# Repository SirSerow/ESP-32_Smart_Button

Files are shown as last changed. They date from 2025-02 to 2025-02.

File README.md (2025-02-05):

# Smart Button with ESP32

## Overview
This project is a **Smart Button** based on the ESP32 microcontroller. The purpose of the project is to make PC operation easy and understandable for older people. With the help of the button, users can trigger predefined actions on their computer, such as opening applications, changing settings, or sending messages.The device is designed to function as a wireless communication interface for triggering predefined actions. The button integrates **ESP-NOW**, **Wi-Fi**, **battery monitoring**, and an **OLED display** for visual feedback. The project includes both **firmware** (ESP32-side) and a **software application** (computer-side) based on C# to control the computer running Windows OS.

## Features
- **ESP-NOW Wireless Communication:** Enables low-latency, direct device-to-device communication.
- **OLED Display (SSD1351, SPI):** Provides visual feedback for the button's status and received commands.
- **Battery Monitoring:** Uses ADC calibration to estimate battery percentage.
- **External Power Detection:** Automatically detects external power and adjusts behavior.
- **Sleep Mode for Power Saving:** The device enters deep sleep when inactive for a certain period.
- **Configurable Timeout Alerts:** Notifies when the button loses connection.
- **ESP-NOW & UART Communication:** Supports both wireless peer-to-peer messaging and wired serial communication.
- **Computer-Side Application:** Monitors the button's status, performs actions on the computer and has an user interface for setting up button actions.

## Hardware Components
- **ESP32 Development Board**
- **SSD1351 OLED Display (SPI)**
- **Push Button**
- **Battery & Charging Circuit**
- **I2C Communication (SDA: GPIO21, SCL: GPIO22)**
- **Status LED (GPIO14)**
- **External Power Detection (GPIO39)**

## Circuit Diagram
The detailed schematic of the **Smart Button** circuit can be found in the [doc folder](./doc/Board_Schematic.pdf).

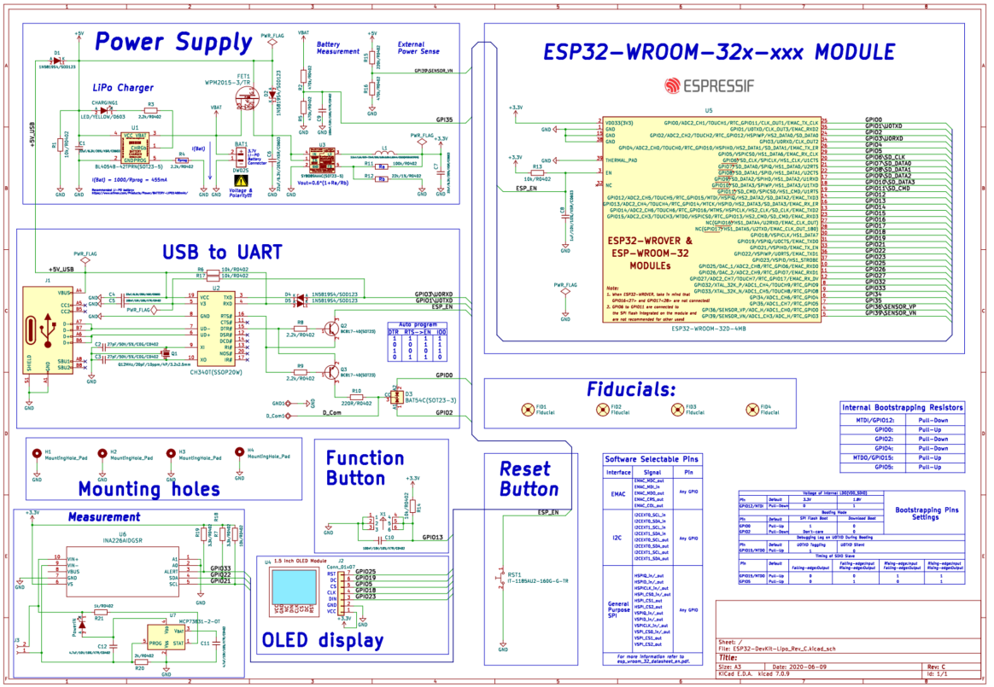
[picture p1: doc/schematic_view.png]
Schematic


## PCB Layout
The project includes a fully designed two-layer PCB for manufacturing. Components are placed exclusevily on top layer to lower the assebly cost and simplify the repairs. For similar reason, in terms of component enclosure type, the preference was given to SMD components. Layout files are available in the hardware folder.

<div align="center" style="margin-top: 30px; margin-bottom: 20px;">
    <b>Top View:</b><br>
    <div style="margin-top: 20px;">
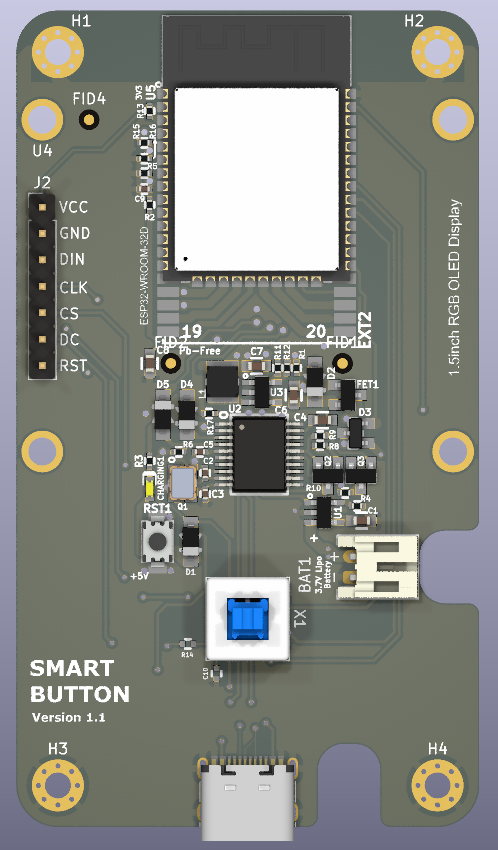
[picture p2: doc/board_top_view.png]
PCB Top
        
    </div>
</div>

<div align="center" style="margin-top: 30px; margin-bottom: 20px;">
    <b>Bottom View:</b><br>
    <div style="margin-top: 20px;">
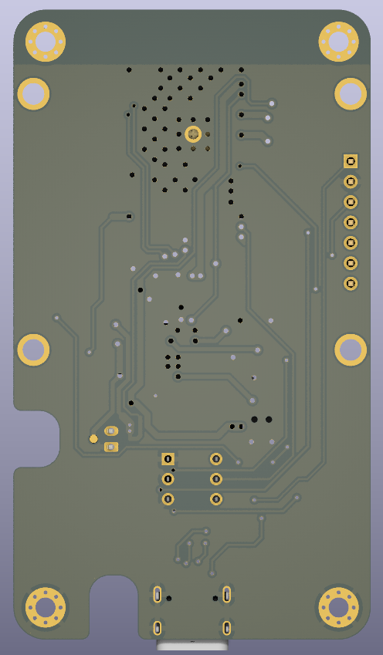
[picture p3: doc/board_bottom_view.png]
PCB Bottom
        
    </div>
</div>

<div align="center" style="margin-top: 30px; margin-bottom: 20px;">
    <b>Side View:</b><br>
    <div style="margin-top: 20px;">
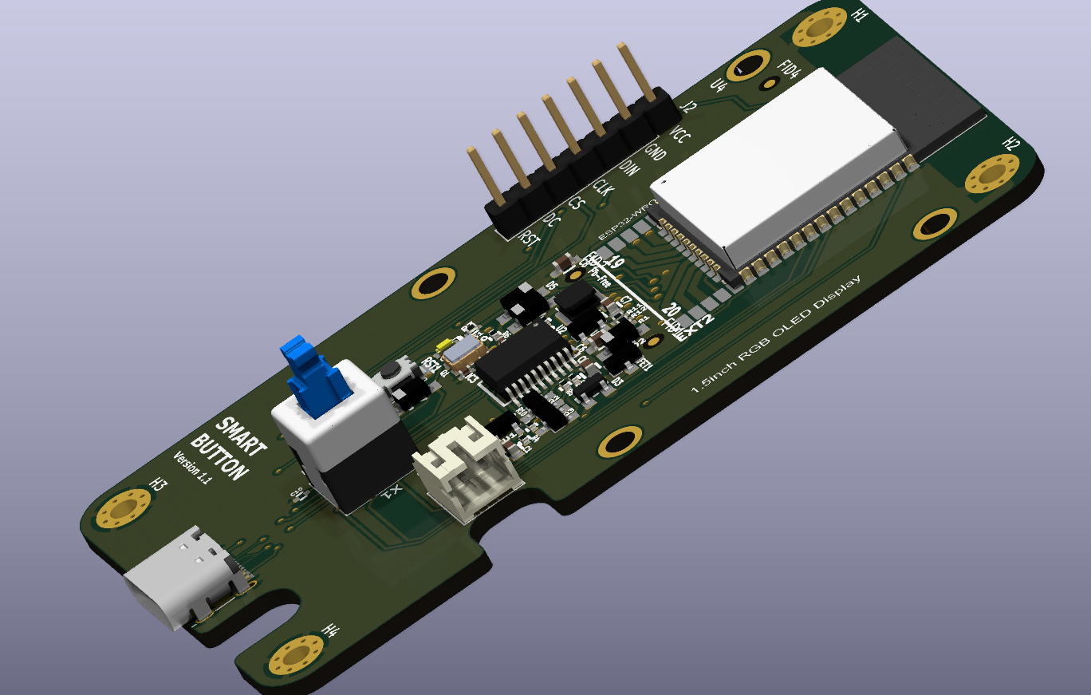
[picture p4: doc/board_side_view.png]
PCB Side
        
    </div>
</div>

## Software Features
The computer-side application for the Smart Button enhances its usability by allowing users to configure and automate various actions triggered by the button press. The application runs as a Windows GUI-based tool, providing an intuitive interface for setting up and managing button actions. 

Since the application is designed to run on Windows, it is developed using C# and .NET Framework. The application communicates with the Smart Button via a serial connection (UART). The framework and communication were chosen to be simple and easy to use and to fit older systems with limited resources.

There are two ways to connect the Smart Button to the computer:
1. **Wired Connection:** The Smart Button is connected to the computer via a USB cable, and the application communicates with the button over a serial port.
2. **Wireless Connection:** The Smart Button communicates with the computer over a wireless connection using the ESP32's ESP-NOW protocol. ESP32 reciever is connected to the computer via USB cable. 

#### **Key Features**
1. **Serial Communication with the Smart Button**
   - Automatically detects the Smart Button via **USB serial ports**.
   - Monitors and logs communication between the button and the PC.
   - Detects button presses and relays corresponding actions.

2. **Configurable Button Actions**
   - Users can assign different actions to the button, such as:
     - **Opening a website (link)**
     - **Making a phone call**
     - **Sending an email**
     - **Launching an application**
   - Each button press executes the assigned function immediately.

3. **Quick Action Setup & Profiles**
   - **User-defined actions** can be assigned to different buttons in the UI.
   - **Multiple configuration profiles** allow quick switching between different use cases.
   - **Preloaded default configurations** available on first launch.

4. **Real-Time Device Status Monitoring**
   - Displays the **current connection status** of the button.
   - Tracks the **last received ping** from the button to ensure connectivity.
   - Shows **battery status** if supported by the Smart Button.

5. **Graphical User Interface (GUI)**
   - Provides a **Windows Forms-based UI** for easy configuration.
   - Displays **icons** for different action types (browser, call, email, application).
   - Supports **customization of button labels and images**.

6. **System Tray Integration**
   - Runs **minimized in the system tray** to remain active in the background.
   - Right-click system tray menu allows quick access to settings and exit options.

7. **Automatic Device Detection**
   - Scans **available COM ports** and attempts to find the button.
   - Provides **visual indicators** if the button is successfully detected.

8. **Error Handling & Debugging Tools**
   - Logs device connection attempts and failures.
   - Displays **error messages** for missing configurations.
   - Allows **manual device selection** if automatic detection fails.

9. **Windows Registry & Configuration Management**
   - Reads and writes **configuration settings** using the **Windows Registry**.
   - Saves **user preferences** such as the default action and last-used settings.

10. **Power & Sleep Monitoring**
   - Tracks **button inactivity** to optimize power usage.
   - Monitors the **last button press time** to prevent unintended actions.
   - Supports **automatic sleep mode handling** if the button is inactive.

<div align="center" style="margin-bottom: 20px;">
    <b>Main App Window:</b><br>
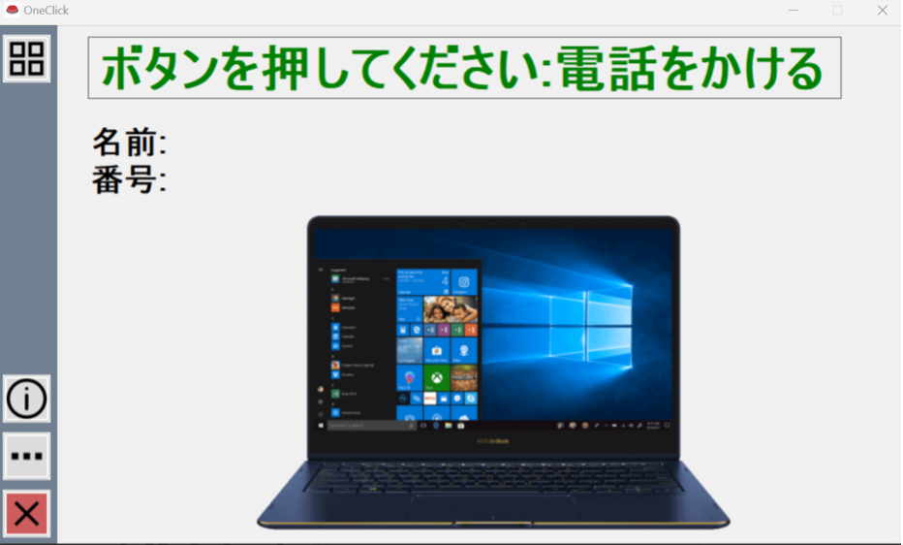
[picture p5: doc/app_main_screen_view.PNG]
Main App Window
    
</div>

<div align="center" style="margin-bottom: 20px;">
    <b>Action Pick:</b><br>
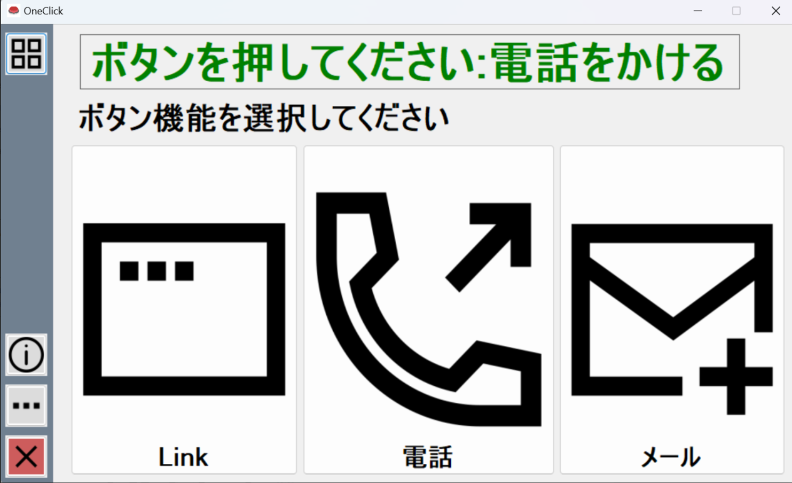
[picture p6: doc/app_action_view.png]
Action Pick
    
</div>

<div align="center" style="margin-bottom: 20px;">
    <b>User Guide:</b><br>
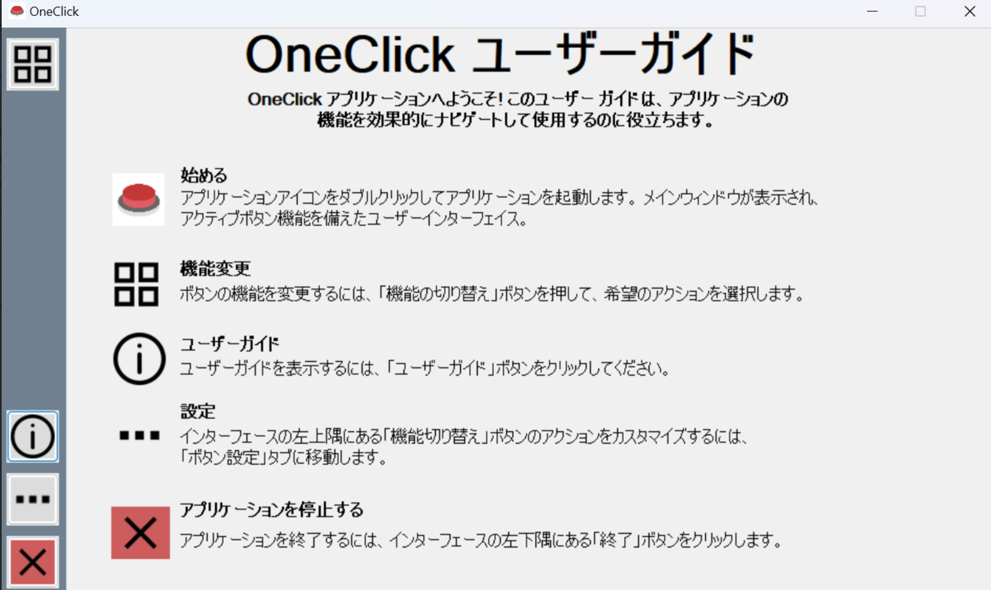
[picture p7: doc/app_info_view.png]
User Guide
    
</div>

## Firmware Overview
The firmware is written using ESP-IDF and structured as follows:

### Key Components:
1. **ESP-NOW Communication**
   - Registers peers for sending/receiving messages.
   - Handles status updates and custom triggers.

2. **Battery & Power Management**
   - Reads battery voltage via ADC.
   - Detects external power and adjusts behavior accordingly.

3. **Sleep Mode**
   - Enters deep sleep mode if inactive for 60 seconds.
   - Wakes up when the button is pressed.

4. **Display Management**
   - Uses LovyanGFX for rendering text/icons.
   - Displays battery percentage, status updates, and alerts.

5. **Button Task**
   - Detects button presses and sends wireless data via ESP-NOW.
   - Provides visual feedback on the OLED screen.

6. **UART Communication**
   - Sends debug messages and status updates via UART.
   - Receives commands from the computer-side application.

7. **Configuration & Settings**
   - Stores default actions and settings in NVS.
   - Allows changing actions via ESP-NOW messages.

8. **Error Handling & Debugging**
   - Logs errors, warnings, and status updates.
   - Provides detailed information for troubleshooting.

## Mechanical Design

The **Smart Button** enclosure is a **custom-designed mechanical housing** that protects internal components while ensuring ease of use. The enclosure consists of **three main parts**:

1. **Top Enclosure** – Contains a **large window** to accommodate the display, ensuring clear visibility.  
2. **Bottom Enclosure** – Designed to securely hold the **PCB and battery**, optimizing space for a compact form factor.  
3. **Button** – A **large, colorful, and easy-to-press button**, providing a tactile and responsive experience.

| Smart Button | Receiver |
|---|---|
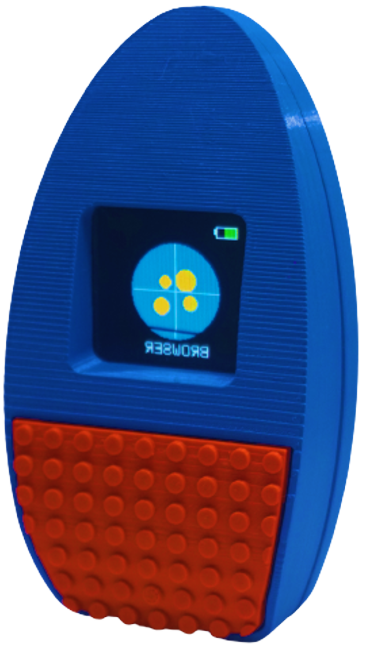
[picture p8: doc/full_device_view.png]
Smart Button
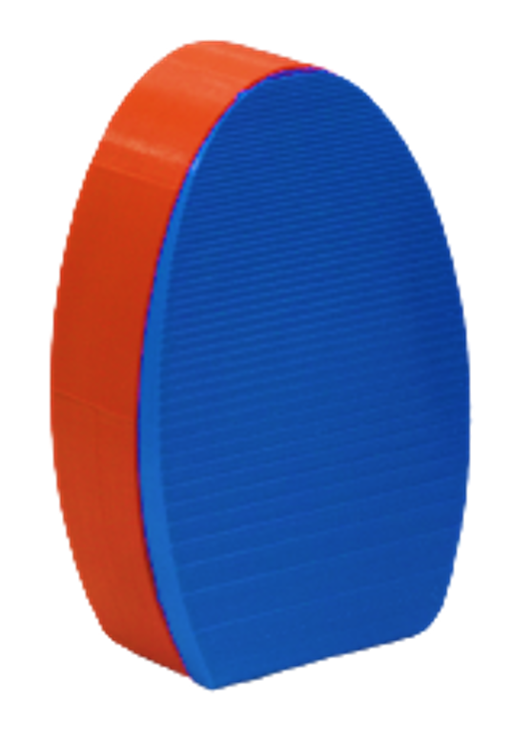
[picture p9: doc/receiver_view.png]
Receiver
|   |   |

#### **Design & Manufacturing**
- The enclosure was designed using **Fusion 360** for precise integration with the PCB and battery.
- The entire assembly is **optimized for 3D printing**, allowing for easy prototyping and customization.
- The button design ensures **smooth actuation** while preventing accidental presses.

#### **Assembly & Fastening**
- Assembly is **simple and efficient**, requiring only **three bolts** to securely hold the enclosure together.
- The button fits into the **top enclosure**, allowing for **firm yet smooth movement** when pressed.

| Main Body Assembly | Receiver Assembly |
|---|---|
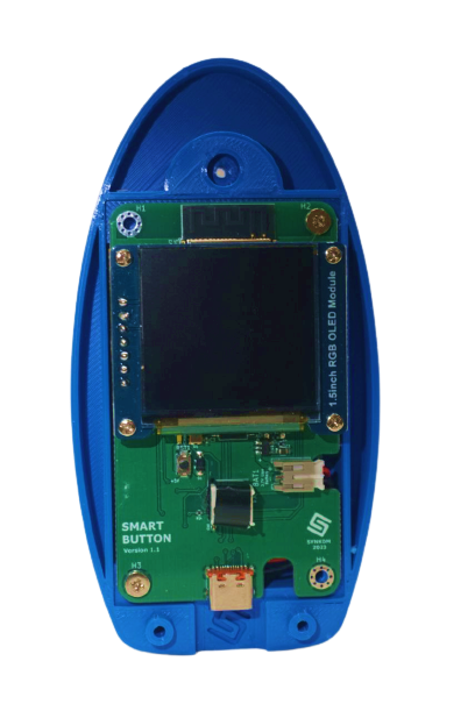
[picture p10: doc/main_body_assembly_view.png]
Main Body Assembly
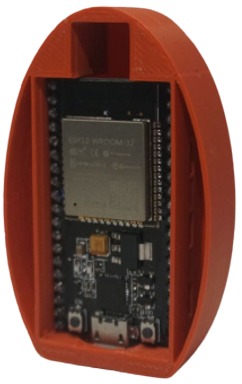
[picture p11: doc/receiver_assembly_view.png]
Receiver Assembly
|   |  |

#### **Customization & Modifications**
- The **3D printable design** allows for easy modifications, such as:
  - Adjusting dimensions for alternative PCB layouts.
  - Customizing button colors and shapes for different applications.
  - Adding ventilation or additional mounting options.

## Usage
The **Smart Button** software provides an intuitive way to configure and use the button for different actions. 
This section explains how to install, configure, and use the software.

#### **1. Installation**
- Download the latest release of the **Smart Button** software.
- Extract the files to a preferred directory.
- Run the **setup.exe** from MagicButtonSetup/Release folder.
- Follow the installation wizard to complete the setup.
- Start the application from the desktop shortcut.

#### **2. Initial Setup**
- On the first launch, the application will prompt you to set up **default actions**.
- Select the desired action for button presses:
  - **Call**: Enter a phone number and contact name.
  - **Email**: Enter an email address and subject.
  - **Application**: Choose an application to launch.
  - **Website**: Enter a URL for quick access.
- Save the settings, and the software will remember them for future use.

#### **3. Connecting the Smart Button**
- Plug the **Smart Button** or receiver device into a USB port.
- The application will attempt to **auto-detect the device**.
- If the device is not detected:
  - Open the **Settings** panel and manually select the COM port.
- Once connected, the UI will show the device **status and connection logs**.

#### **4. Configuring Button Actions**
- Navigate to the **Button Setup** panel.
- Assign actions to different button presses:
  - **Short Press** → Quick Action (e.g., Open a website)
  - **Long Press** → Secondary Action (e.g., Make a call)
  - **Double Press** → Custom Action (e.g., Launch an application)
- Click **Save** to apply the changes.

#### **5. Using the Smart Button**
- **Single press** executes the assigned action.
- **Holding the button** triggers an alternative action.
- **Double-clicking** performs a special function (e.g., emergency contact).
- The system tray icon will show notifications about the current action.

#### **6. Monitoring Status & Logs**
- The **Main Dashboard** displays:
  - **Device Connection Status**
  - **Last Button Press Timestamp**
  - **Current Battery Level** (if supported)
  - **Recent Logs & Debug Messages**
- If the button loses connection, the software will display a **warning**.

#### **7. System Tray & Background Mode**
- The application can be minimized to the **system tray** for background operation.
- Right-click the tray icon to:
  - **Open Settings**
  - **Reconnect the Button**
  - **Exit the Application**

#### **8. Resetting & Troubleshooting**
- If the button stops responding:
  - Check the **USB connection**.
  - Restart the application and ensure the device is detected.
  - Use the **Reset Device** option in the settings.
  - Check device **battery level** and **power source**.

#### **9. Power Management & Sleep Mode**
- If the button is inactive for a long period:
  - It will enter **power-saving mode**.
  - The application will notify the user if a connection is lost.
  - The button can be **reactivated** with a press.
- The software monitors **battery percentage** and alerts the user if charging is needed.

## Future Enhancements
- **BLE Integration** for mobile applications.
- **Multi-button Pairing** for grouped communication.
- **Cloud Connectivity** via MQTT for IoT applications.

## Known issues
- **Battery Monitoring:** The battery percentage calculation may not be accurate due to voltage fluctuations.
- **PCB Design:** The butto component placement and connection has to be reconsidered, currently connection has to be manually fixed. The PCB layout may require further optimization for mass production.
- **ESP-NOW Communication:** The wireless communication may be affected by interference or distance limitations.

## License
This project is open-source under the **MIT License**.

## Acknowledgements
Special thanks to **Espressif** for the **ESP32** platform and **LovyanGFX** for display handling. The PCB design was based on [ESP32-DevKit-Lipo](https://github.com/OLIMEX/ESP32-DevKit-LiPo/tree/master) by Olimex, original files were changed to adapt to the project requirements.

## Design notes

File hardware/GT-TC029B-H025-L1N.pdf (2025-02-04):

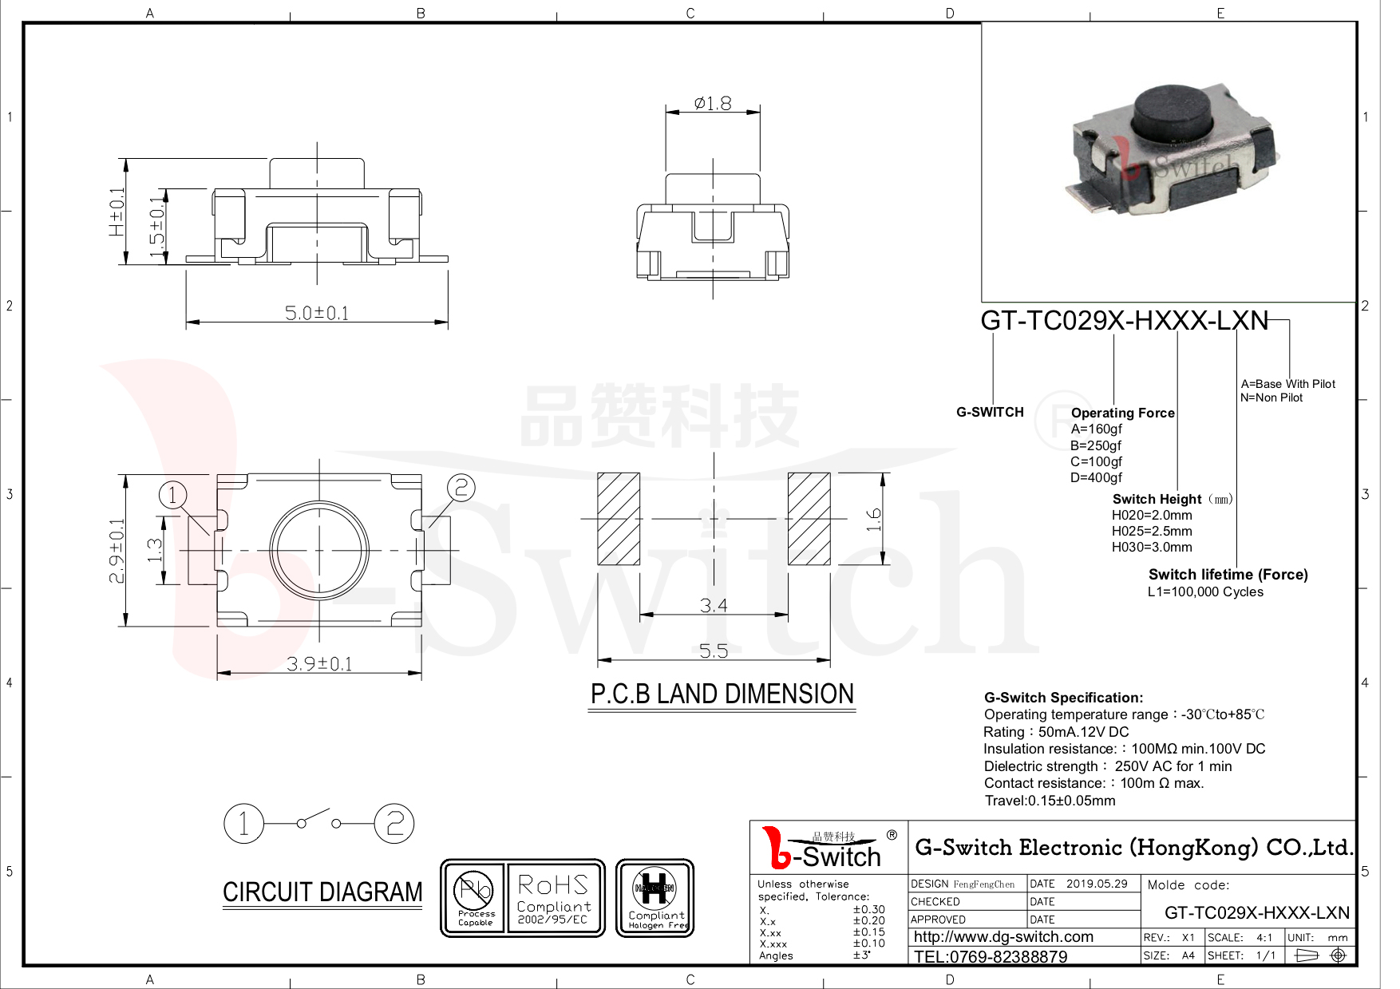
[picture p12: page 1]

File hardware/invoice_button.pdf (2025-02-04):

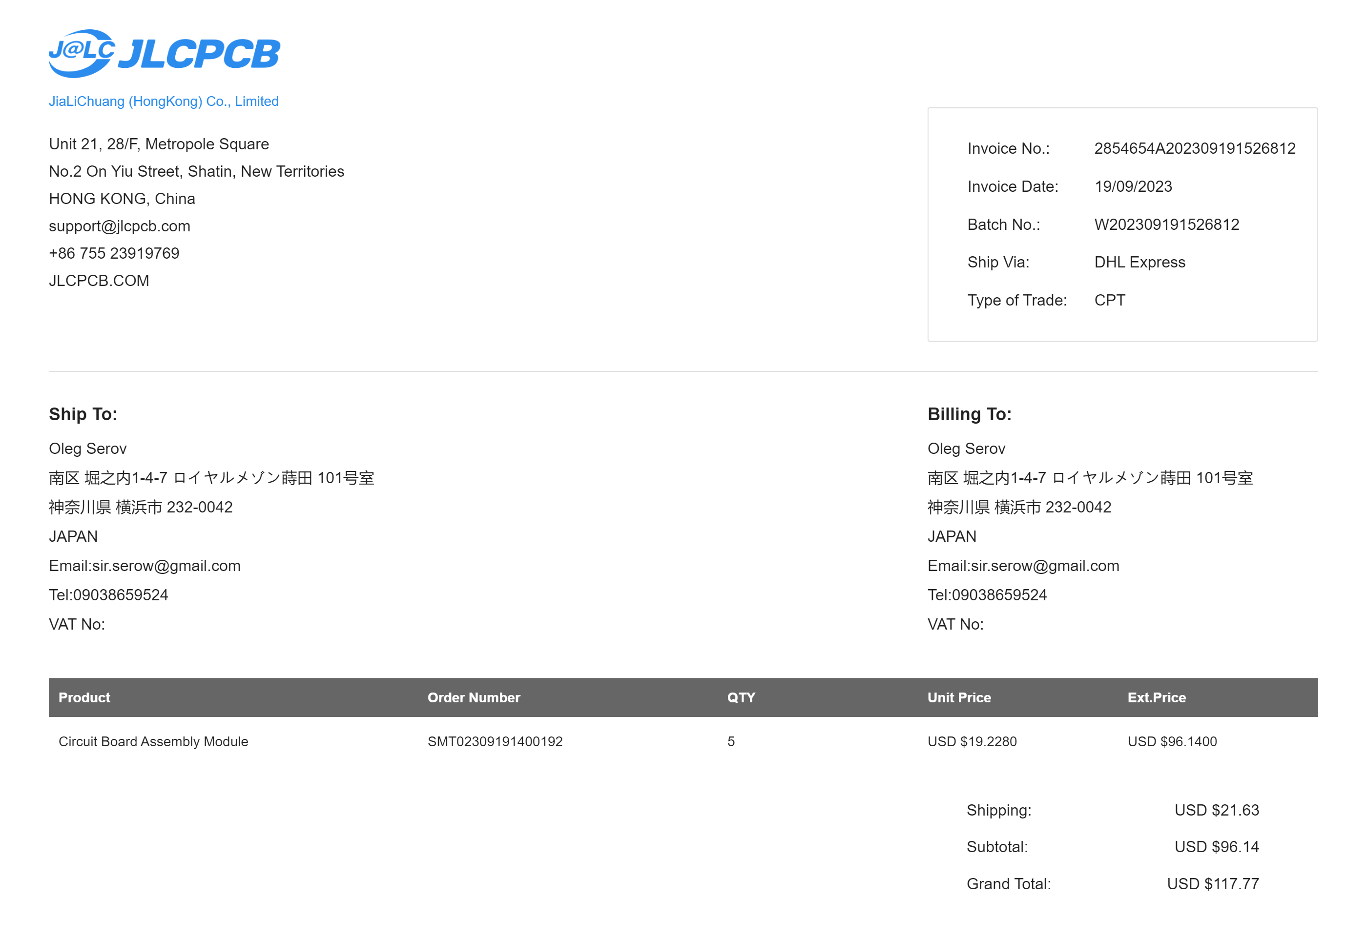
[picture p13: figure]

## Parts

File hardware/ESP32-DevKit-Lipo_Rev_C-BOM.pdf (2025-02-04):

16:26:48 | ESP32-DevKit-Lipo_Rev_C-BOM 03/19/2020
Quantity | Designation | Package | Designator
1 | 220R/R0402 | R0402 | R10
4 | 2.2k/R0402 | R0402 | R3,R4,R8,R9
4 | 10k/R0402 | R0402 | R1,R6,R13,R17
1 | 49.9k/1%/R0402 | R0402 | R12
2 | 220k/R0402 | R0402 | R11,R15
3 | 470k/R0402 | R0402 | R2,R5,R16
1 | 2.2uH/1.5A/DCR=72mR/20%/ 3.00x3.00x1.50mm/ CD32(NR3015T2R2M) | CD32 | L1
2 | 27pF/50V/5%/C0G/C0402 | C0402 | C2,C3
2 | 100nF/10V/10%/X7R/C0402 | C0402 | C5,C9
1 | 1uF/10V/10%/X5R/C0603 | C0603 | C8
4 | 22uF/6.3V/20%/X5R/C0603 | C0603 | C4,C1,C6,C7
1 | LED/YELLOW/0603 | LED_0603 | CHARGING1
1 | BAT54C(SOT23-3) | SOT23-3 | D3
4 | 1N5819S4/SOD123 | SOD-123 | D1,D2,D4,D5
2 | BC817-40(SOT23) | SOT23 | Q2,Q3
1 | WPM2015-3/TR | SOT23 | FET1
1 | BL4054B-42TPRN(SOT23-5) | SOT-23-5 | U1
1 | CH340T(SSOP20W) | SSOP-20W | U2
1 | SY8089AAAC(SOT23-5) | SOT-23-5 | U3
1 | Q12MHz/20pF/10ppm/4P/3.2x2.5mm | TSX-3.2x2.5mm | Q1
1 | MISB-SWMM-5B-LF(USB_MICRO) | MISB-SWMM-5B_LF | USB-UART1
1 | IT-1185AU2-160G-G-TR | IT1185AU2 | RST1
1 | DW02S | DW02S | BAT1
2 | HN1x19 | HN1x19 | EXT1,EXT2
1 | ESP32-WROOM-32D-4MB | ESP32-MODULE_Universal | U5
3 | Opened | SJ
1 | NA/R0402 | R0402 | R7 BAT_PWR_E1, BAT_SENS_E1, PWR_SENS_E1

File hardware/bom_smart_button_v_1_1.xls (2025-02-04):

Comment | Designator | Footprint | JLCPCB Part #
BL4054B-42TPRNSOT-23-5BatteryManagementICsROHS | U1 | SOT23-5 | C83783
ESP32-WROOM-32D-N4 | U5 | SMD,18x25.5mm | C473012
22uF6.3V20%X5R | C1,C4,C6,C7 | 0603 | C342824
S2B-PH-KL(LF)(SN) | BAT1 | S2B-PH-KL(LF)(SN) | C160237
62.5mWThickFilmResistors?100ppm/??5%470k?0402ChipResistor-SurfaceMountROHS | R2,R5,R16 | 0402 | C227380
100nF10V10%X7R | C5,C9,C10 | 0402 | C343042
27pF50V5%C0G | C2,C3 | 0402 | C513447
20V2.2A800mW110m?@4.5V,2.7APChannelSOT-23MOSFETsROHS | FET1 | SOT-23 | C558305
62.5mWThickFilmResistors?100ppm/??1%10k?0402ChipResistor-SurfaceMountROHS | R1,R6,R13,R14,R17 | 0402 | C60490
NoNO50mA100M?100000Times12V250gf@?30gfBricknoggingSPSTSMDTactileSwitchesROHS | RST1 | SMD | C843669
CH340T | U2 | SSOP-20-208mil | C8689
PZ254V-11-07P | J2 | Plugin,P=2.54mm | C492406
USB2.05A1SurfaceMount16PFemale-40?~+85?GoldHighConductivityCopperType-CSMDUSBConnectorsROHS | J1 | SMD | C963413
62.5mWThickFilmResistors?100ppm/??1%220?0402ChipResistor-SurfaceMountROHS | R10 | 0402 | C112291
62.5mWThickFilmResistors?100ppm/??1%2.2k?0402ChipResistor-SurfaceMountROHS | R3,R4,R8,R9 | 0402 | C114762
2.2uH1.5ADCR=72mR20%3.00x3.00x1.50mm(NR3015T2R2M) | L1 | CD32 | C86423
1N5819S4 | D1,D2,D4,D5 | SOD123 | C2939006
XKB8080-W | X1 | Plugin | C318861
BAT54C | D3 | SOT23-3 | C909965
CR0402-JW-104GLF | R11 | 0402 | C203104
CR0402JF0224G | R15 | 0402 | C100616
1uF10V10%X5R | C8 | 0603 | C106214
Q12MHz20pF10ppm4P3.2x2.5mm | Q1 | SMD3225-4P | C2933035
SY8089AAACSOT-23-5DC-DCConvertersROHS | U3 | SOT-23-5 | C479074
45V300mW40@500mA,1V500mANPNSOT-23BipolarTransistors | Q2,Q3 | SOT23 | C475629
LEDYELLOW | CHARGING1 | 0603 | C397049
AECR0402F22K0K9 | R12 | 0402 | C328311

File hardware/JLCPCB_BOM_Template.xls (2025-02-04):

Comment | Designator | Footprint | JLCPCB Part#(optional)
100uF | C1 | CASE-B_3528 | C16133
100nF | C2, C9, C10 | 0603 | C14663
300KΩ | R4, R7 | 0603 | C23024
15KΩ | R5, R6 | 0603_R | C22809
100KΩ | R1, R3 | 0603_R | C25803
10uF | C3-5 | 1206_C | C13585
100Ω | R2 | 0603_R | C22775
1N4148WS | D1 | SOD-323 | C2128
LM358DR2G | U1 | SOIC-8_150mil | C7950
HT7550-1 | VR1 | SOT-89(SOT-89-3) | C16106

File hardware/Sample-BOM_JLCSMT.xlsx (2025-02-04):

Comment | Designator | Footprint | JLCPCB Part #（optional）
100uF | C1 | CAP-SMD_L3.5-W2.8 | C16133
15K | R5,R6 | R0603 | C22809
DC-005-20A_C136744 | DC1 | DC-IN-TH_DC-005-20A | C136744
Header-Female-2.54_1x8 | P2,P3 | HDR-TH_8P-P2.54-V | C27438
K2-1102DP-C4SW-04 | SW1 | KEY-TH_4P-L6.0-W6.0-P4.50-LS6.5 | C110153
ATMEGA328P-PU | U1 | DIP-28_L34.6-W7.3-P2.54-LS10.2-BL | C33901
670688000 | USB1 | USB-B-TH_67068-8000 | C114097

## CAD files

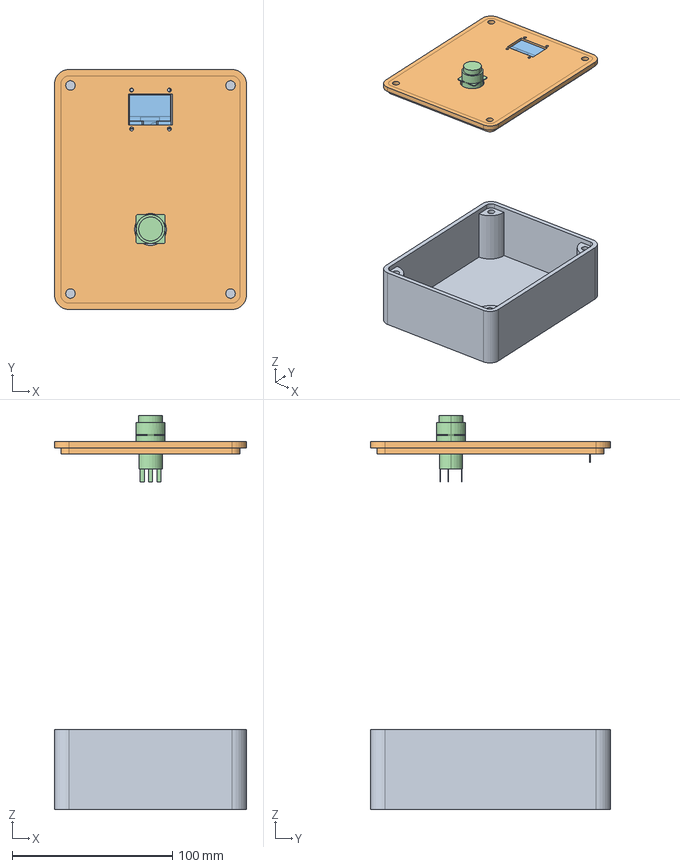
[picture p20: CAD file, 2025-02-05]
mechanical/Assembly.FCStd
120.0 x 150.0 x 246.2 mm
enclosure_001
lid_001
OLED Display 0.96_1_001
pushbutton_switch_LAS-AY1_001

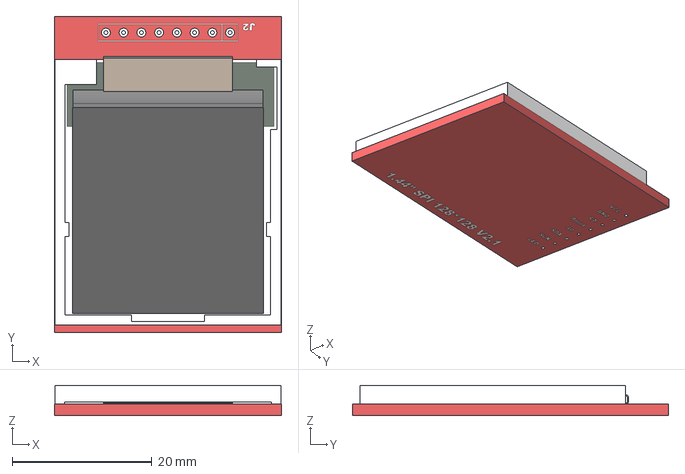
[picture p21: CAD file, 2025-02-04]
hardware/1-44in-lcd-tft-1.snapshot.6/1.44in SPI LCD Module - No Glass.stp
32.5 x 45.2 x 4.32 mm

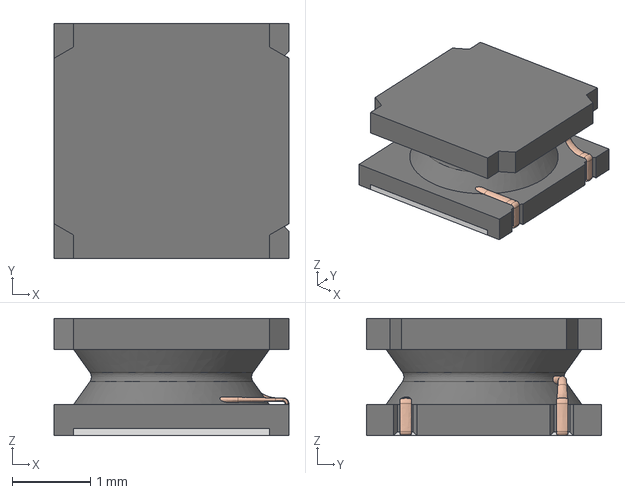
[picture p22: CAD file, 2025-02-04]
hardware/3d/L-CD32_shielded.step
3.00 x 3.00 x 1.50 mm

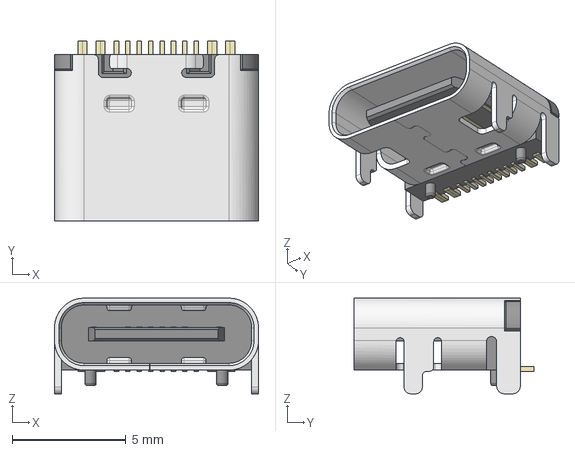
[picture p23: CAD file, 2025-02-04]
hardware/3d/port/HRO_TYPE-C-31-M-12.step
8.95 x 7.90 x 4.20 mm

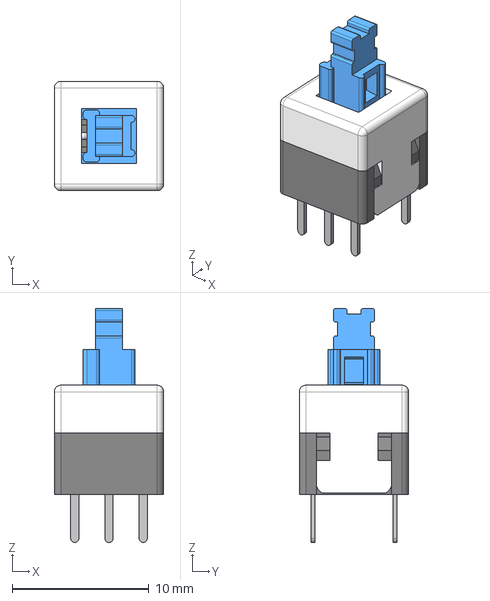
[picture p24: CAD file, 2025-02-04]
hardware/3d/push-switch-8x8-6pin-with-lock-1.snapshot.1/Push Switch_8x8_6pin_with Lock.stp
8.00 x 8.00 x 17.1 mm

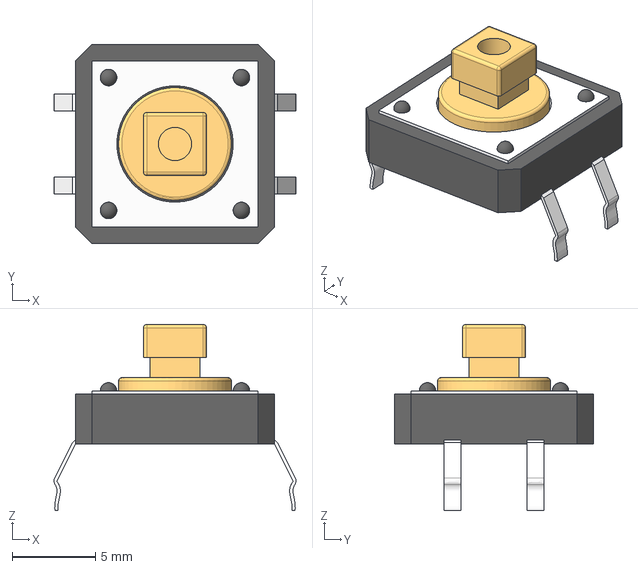
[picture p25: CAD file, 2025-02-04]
hardware/button-12x12-1.snapshot.1/button 12x12/button 12x12.step
14.6 x 12.0 x 11.2 mm

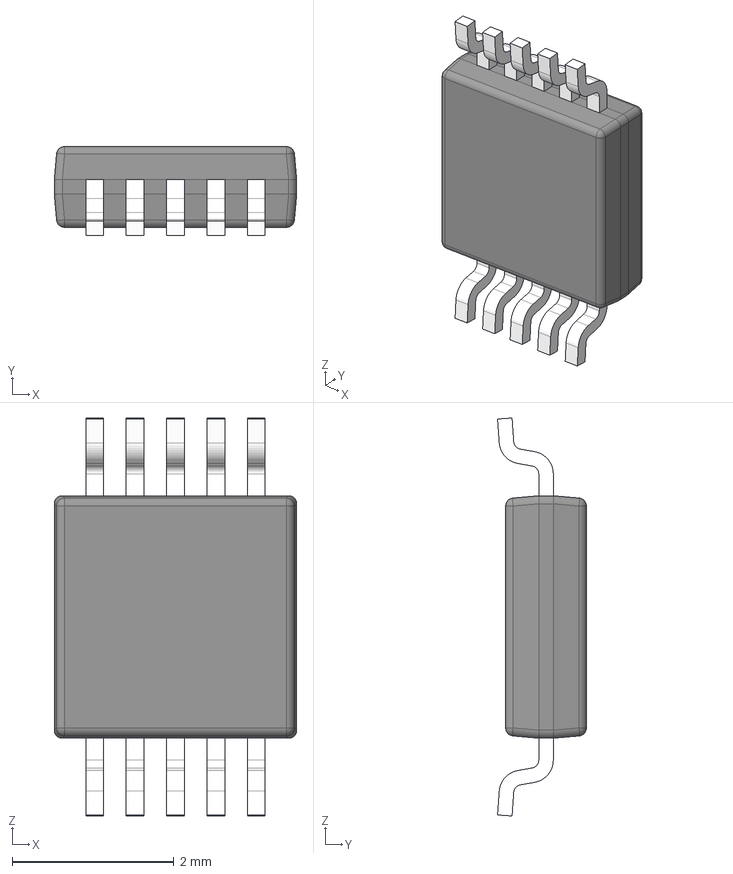
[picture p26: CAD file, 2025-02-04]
hardware/ul_INA226AIDGSR/DGS0010A.stp
3.00 x 1.10 x 4.93 mm
BODY-SO
LEAD-SO x 10
PIN1-ID

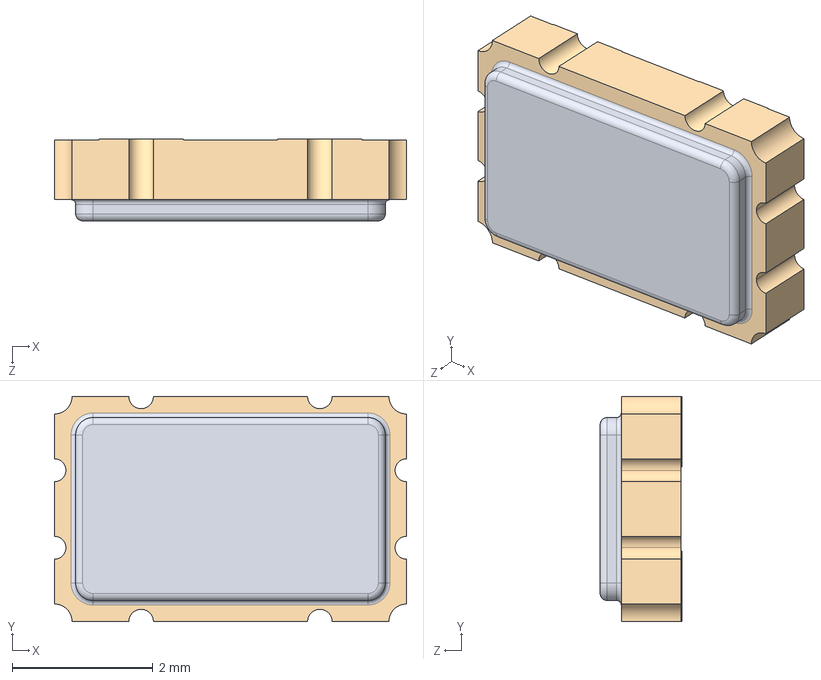
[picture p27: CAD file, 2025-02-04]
hardware/3d/QSG5032.step
5.00 x 3.20 x 1.16 mm

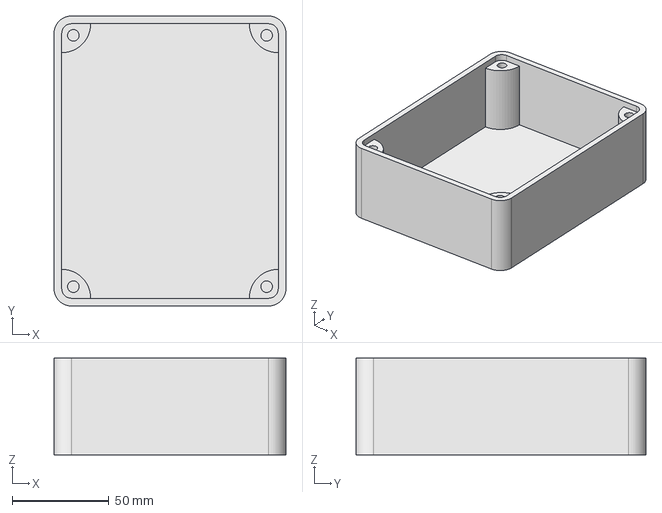
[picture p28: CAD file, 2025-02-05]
mechanical/enclosure.FCStd
120.0 x 150.0 x 50.0 mm

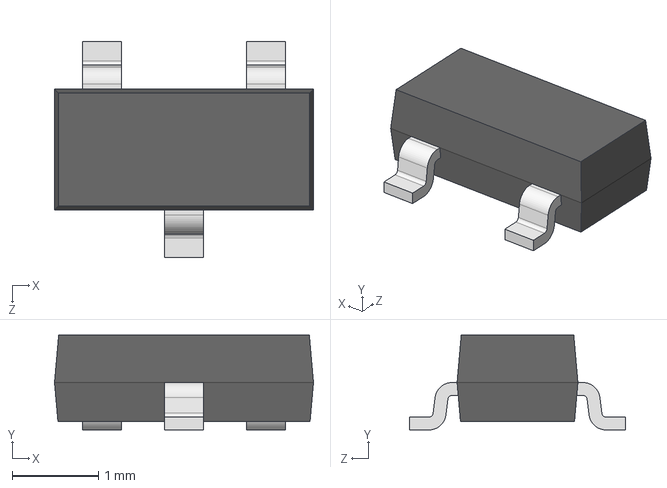
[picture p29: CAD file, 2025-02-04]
hardware/3d/SOT-23.step
3.00 x 1.10 x 2.50 mm

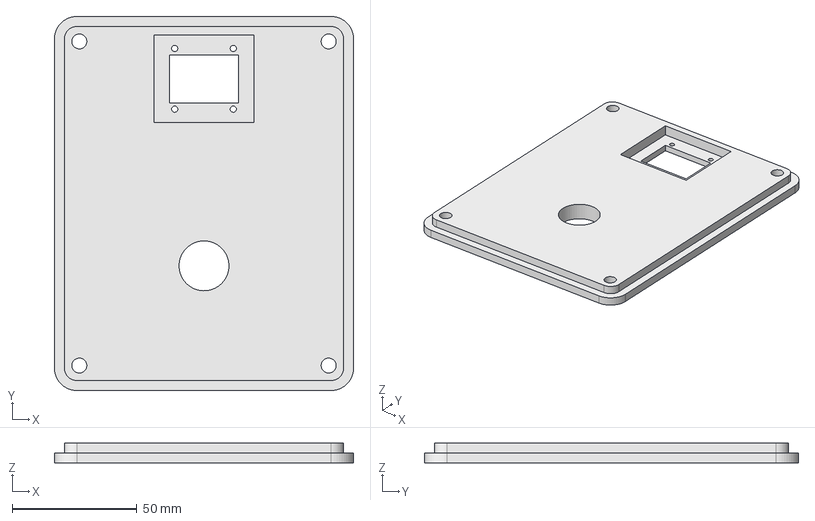
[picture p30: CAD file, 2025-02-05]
mechanical/lid.FCStd
120.0 x 150.0 x 8.00 mm

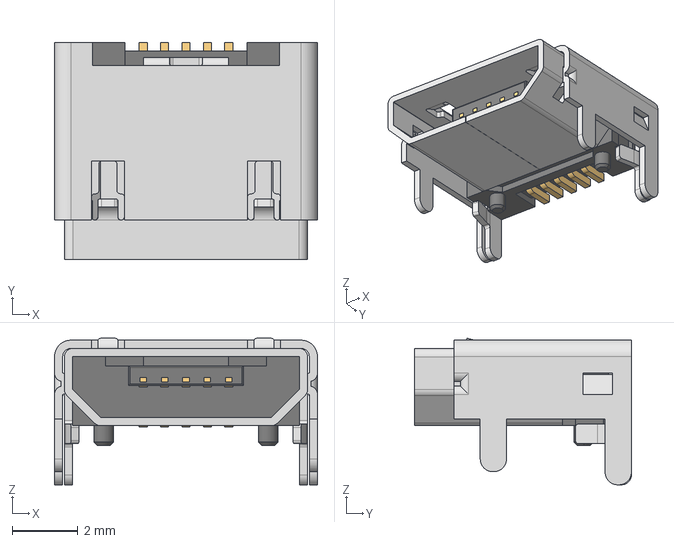
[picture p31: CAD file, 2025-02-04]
hardware/3d/usb_micro_4p.stp
8.00 x 6.60 x 4.46 mm

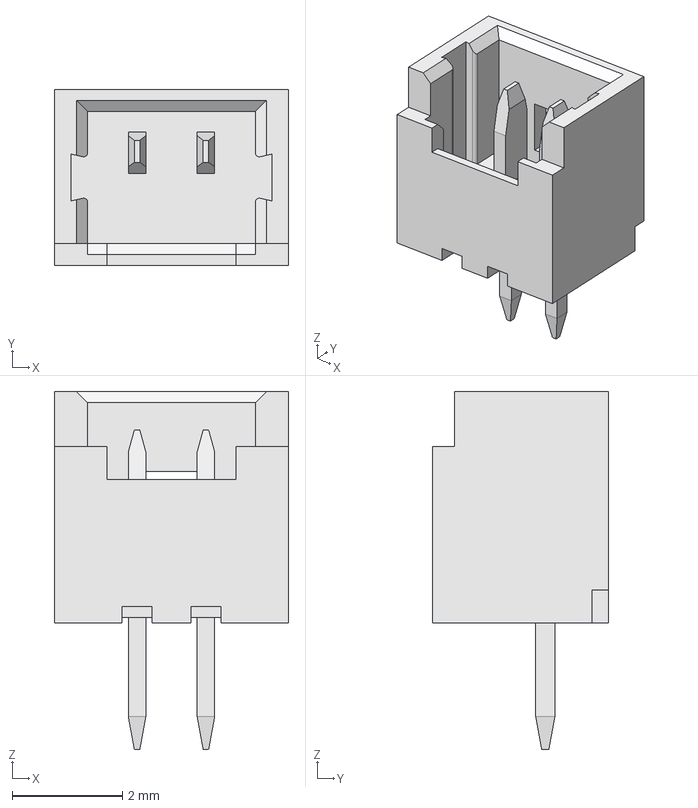
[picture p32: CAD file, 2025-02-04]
hardware/3d/Molex_PicoBlade_530470210.step
4.25 x 3.20 x 6.50 mm

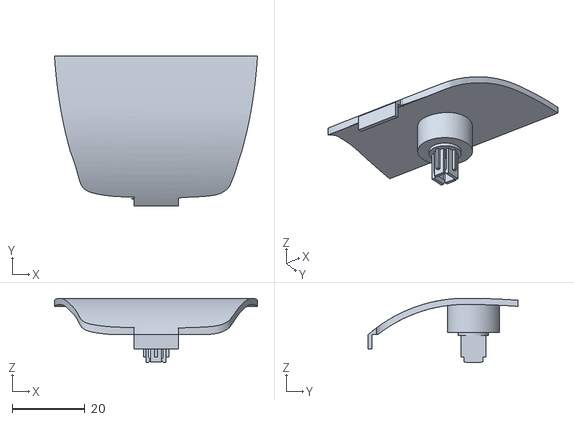
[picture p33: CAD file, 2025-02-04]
hardware/3d/Mouse_button.stl
55.9 x 41.2 x 17.7

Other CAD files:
hardware/3d/Mouse_Button_V3.stl
hardware/3d/Oval_Top_V2.stl
hardware/3d/Button_top_v2.stl
hardware/3d/switch_modify.stl
hardware/3d/BAT54.step
hardware/3d/ESP32-WROOM-32D-56544.STEP
hardware/3d/HN1x19-PinHeader_1x19_P2.54mm_Vertical.step
hardware/3d/Mouse_Button_V3 - Copy.stl
hardware/3d/Mouse_Button_corrected.stl
hardware/3d/Mouse_button_v1.stl
hardware/3d/Mouse_button_v2.stl
hardware/3d/Oval_Bottom_v2.stl
hardware/3d/SOD123.step
hardware/3d/SOT-23-5.step
hardware/3d/it1185.step
hardware/ul_INA226AIDGSR/DGS0010A.stl

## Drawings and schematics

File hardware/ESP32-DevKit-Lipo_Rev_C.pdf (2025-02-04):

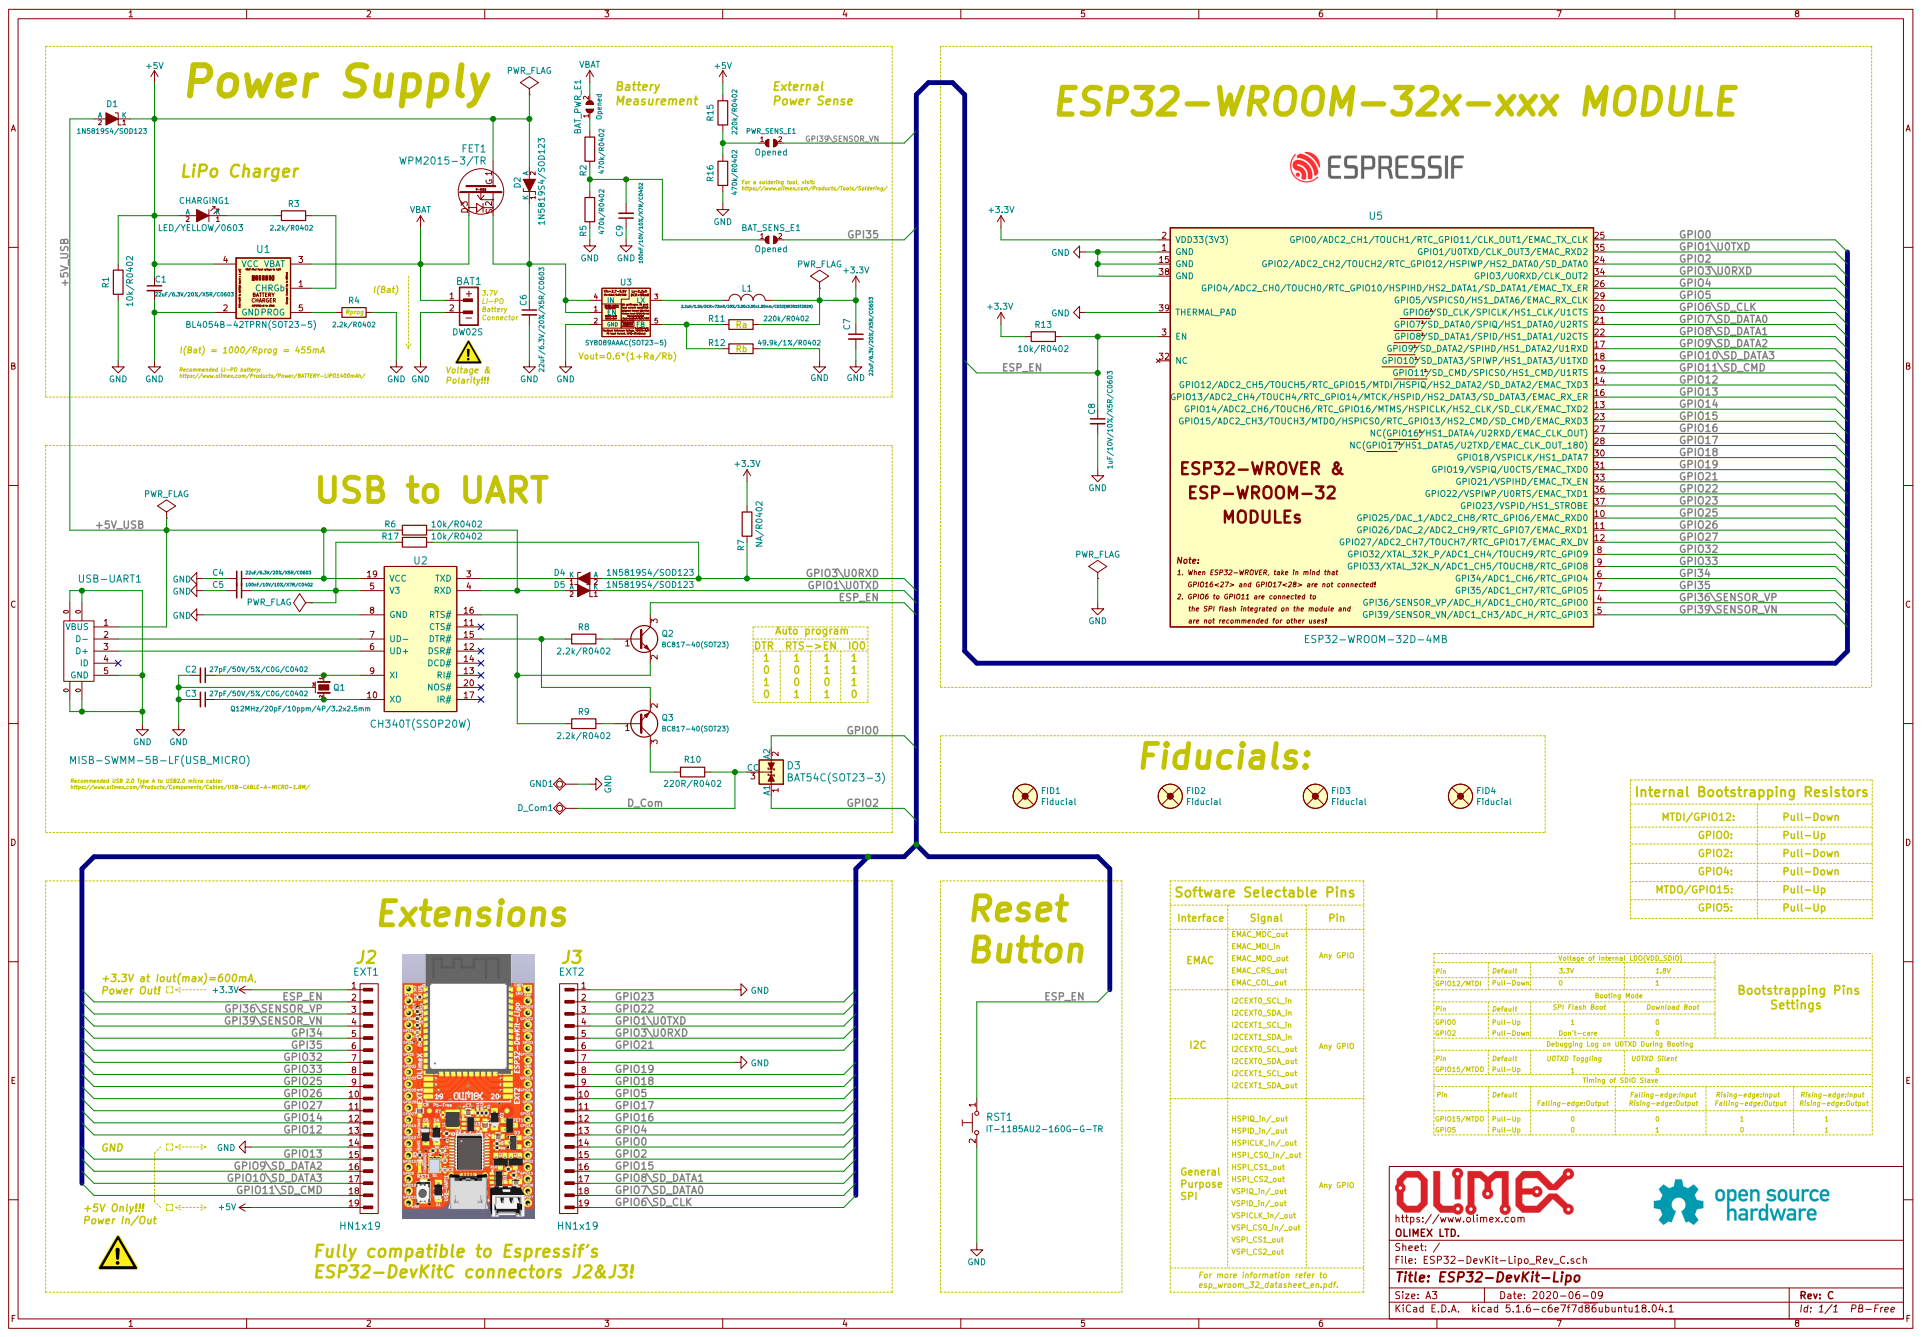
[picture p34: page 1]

0 ESP32-WROOM-32x-xxx MODULE
I(Bat) Fully compatible to Espressif's

load current capability! Lx=2.2uH

Do not float. Enable control. FB Input Current, I(FB)=50nA(max) Feedback Reference Voltage, V(REF)=0.6V

2.2. 2. 2.2. 2. 2. GPIO6 to GPIO11 are connected to are not recommended for other uses! ESP-WROOM-32

Recommended LI-PO battery: https://www.olimex.com/Products/Power/BATTERY-LIPO1400mAh/

1. 1. 1. When ESP32-WROVER, take in mind that
ESP32-WROVER &

1 Debugging Log on U0TXD During Booting USB to UART

GPIO16<27> and GPIO17<28> are not connected! MODULEs

Interface

I2CEXT0_SCL_in EMAC

Falling-edge:Output Any GPIO

+5V Only!!! Power In/Out

Id: 1/1 PB-Free Title: ESP32-DevKit-Lipo

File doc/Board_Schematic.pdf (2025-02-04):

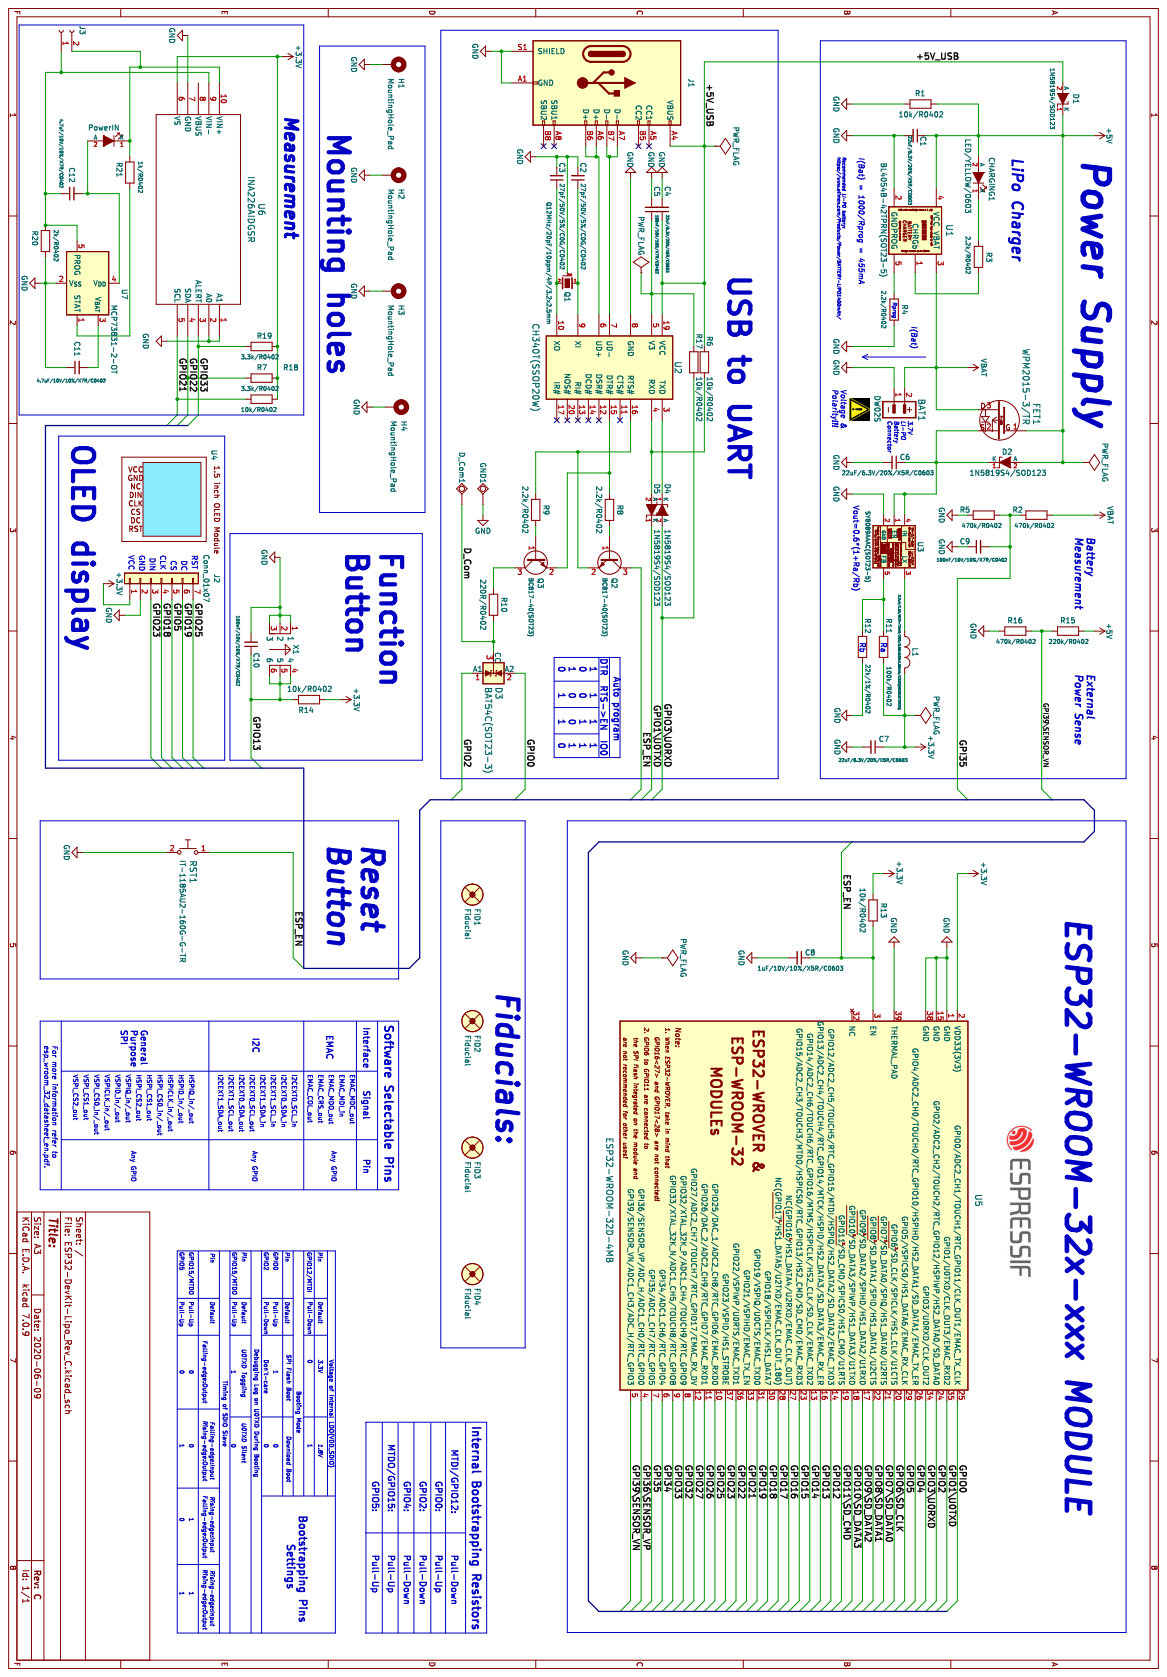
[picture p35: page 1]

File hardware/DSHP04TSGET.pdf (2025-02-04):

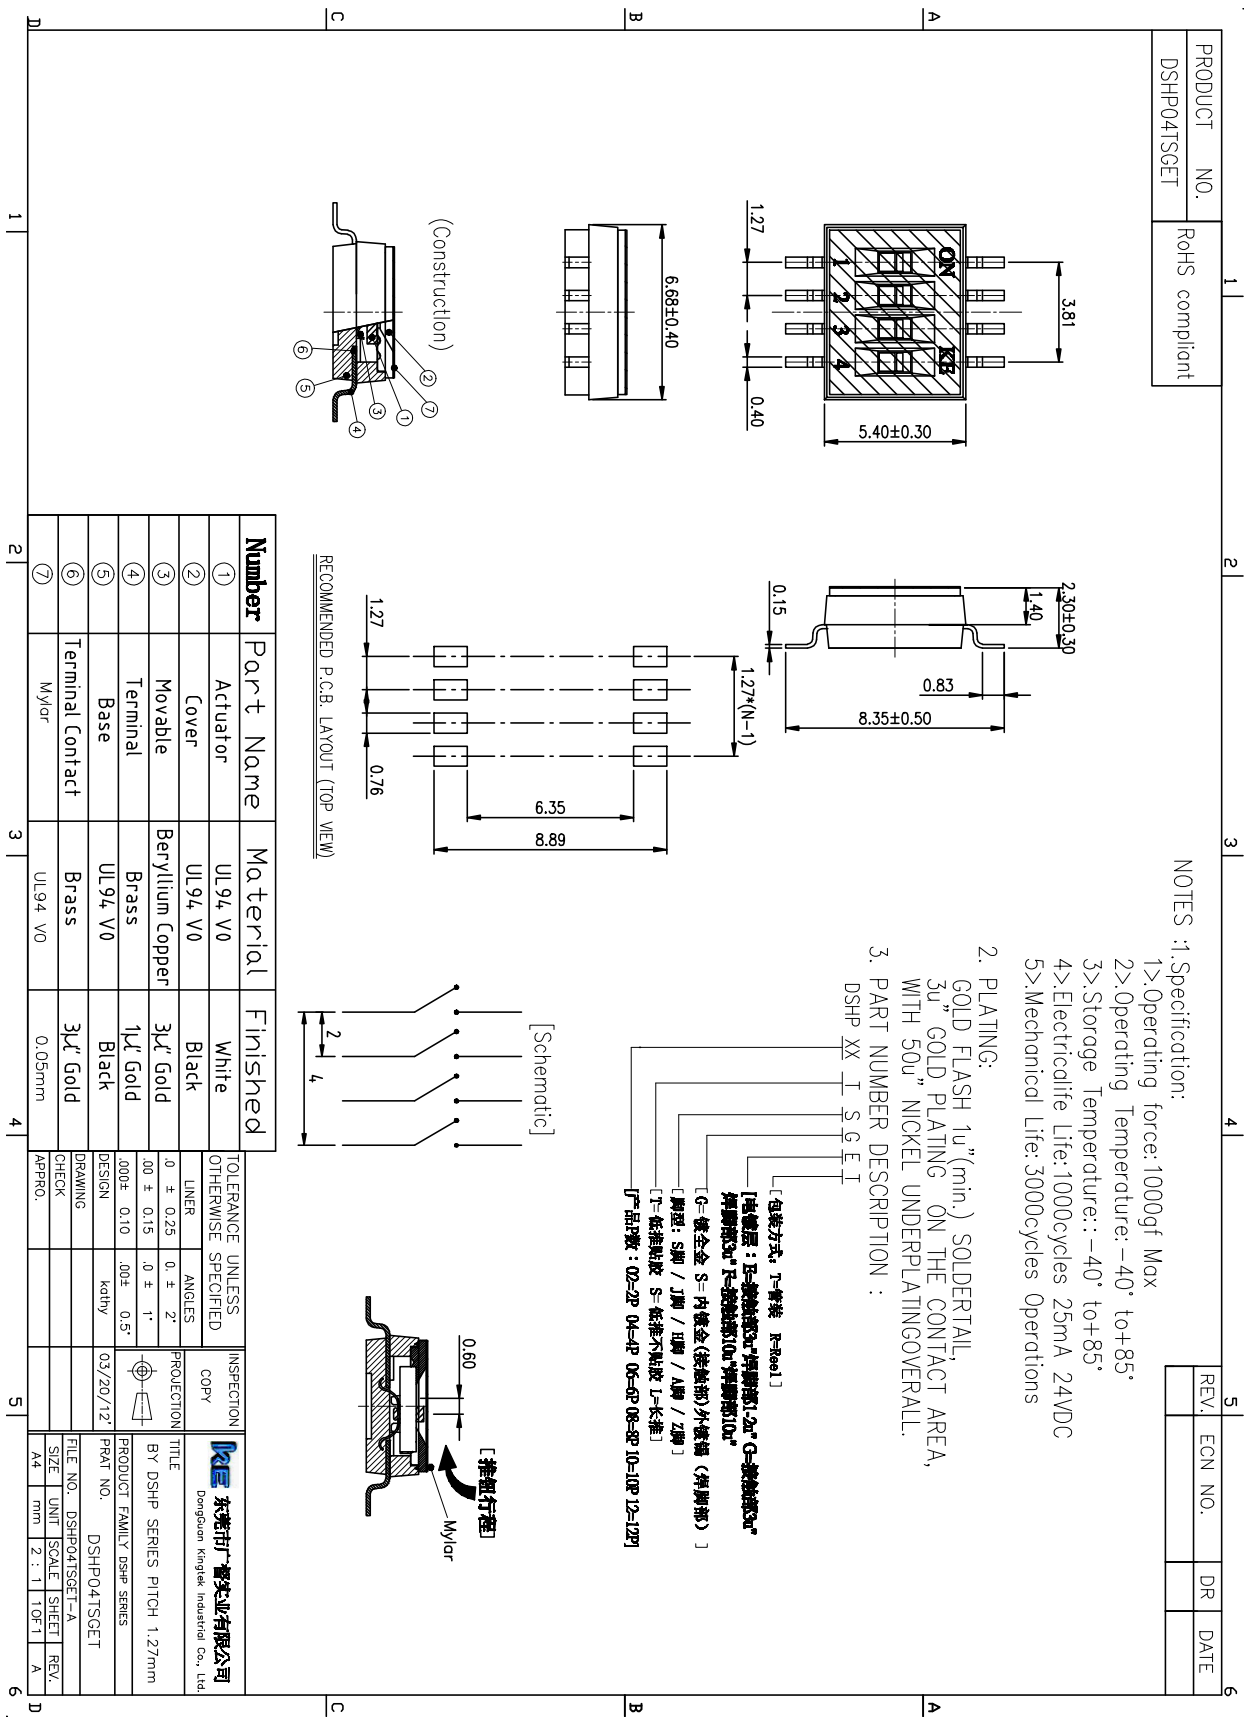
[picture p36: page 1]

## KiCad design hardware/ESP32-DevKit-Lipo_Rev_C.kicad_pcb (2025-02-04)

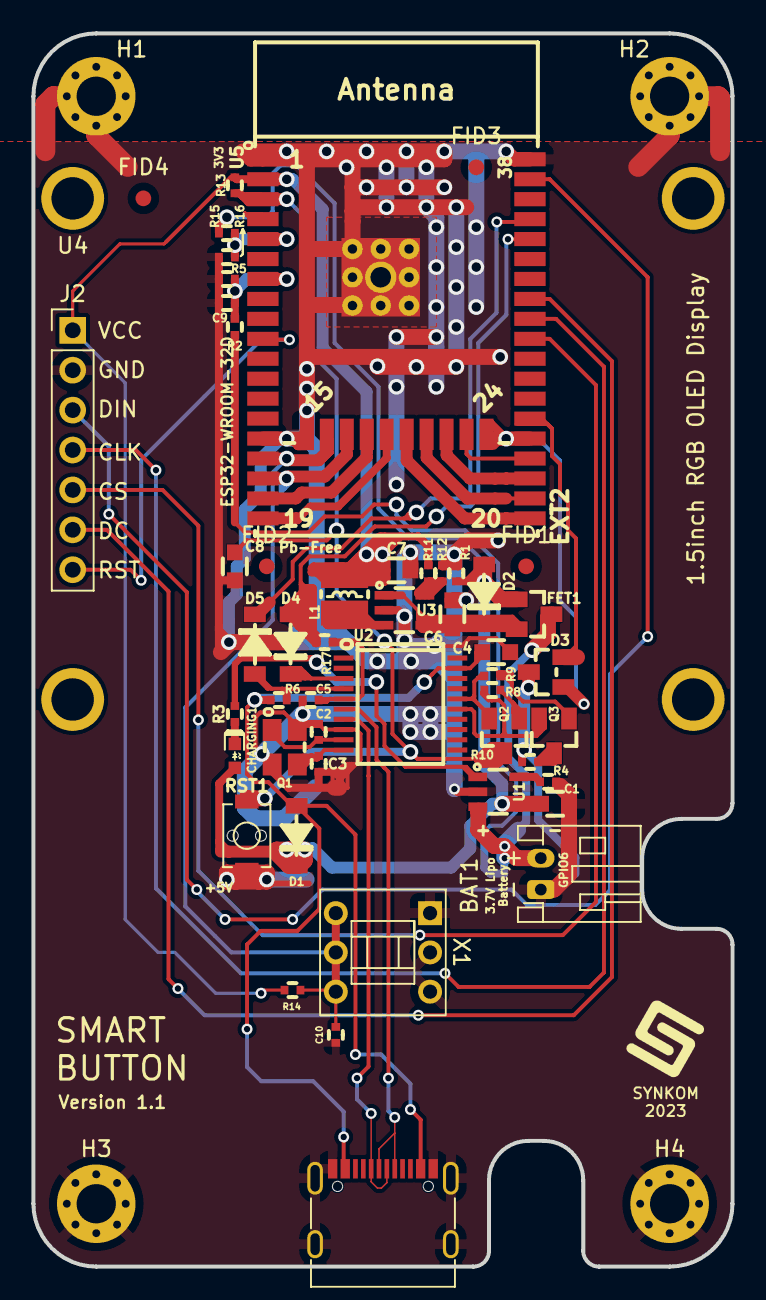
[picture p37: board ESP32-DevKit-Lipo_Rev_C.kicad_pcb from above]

Board: 2 copper layers, 44.5 x 78.5 mm, 56 parts (1 on the bottom side), 37 nets.

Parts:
BAT1: DW02S; JST_PH_S2B-PH-K_1x02_P2.00mm_Horizontal
C1, C4, C6, C7: 22uF/6.3V/20%/X5R/C0603; C_0603_5MIL_DWS
C2, C3: 27pF/50V/5%/C0G/C0402; C_0402_5MIL_DWS
C5, C9, C10: 100nF/10V/10%/X7R/C0402; C_0402_5MIL_DWS
C8: 1uF/10V/10%/X5R/C0603; C_0603_5MIL_DWS
CHARGING1: LED/YELLOW/0603; LED_0603_KA
D1, D2, D4, D5: 1N5819S4/SOD123; SOD-123_1C-2A_KA
D3: BAT54C(SOT23-3); SOT23-3
D_Com1: TESTPAD; TESTPAD_40-ROUND
FET1: WPM2015-3/TR; SOT23
FID1, FID2, FID3, FID4: Fiducial; Fiducial_1mm_Mask2mm
H1, H2, H3, H4: MountingHole_Pad; MountingHole_2.5mm_Pad_Via
J1: USB_C_Receptacle_USB2.0; USB_C_Receptacle_G-Switch_GT-USB-7010ASV
J2: Conn_01x07; PinHeader_1x07_P2.54mm_Vertical
L1: 2.2uH/1.5A/DCR=72mR/20%/3.00x3.00x1.50mm/CD32(NR3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; CD32
Q1: Q12MHz/20pF/10ppm/4P/3.2x2.5mm; TSX-3.2x2.5mm_GND(3)
Q2, Q3: BC817-40(SOT23); SOT23
R1, R6, R13, R14, R17: 10k/R0402; R_0402_5MIL_DWS
R2, R5, R16: 470k/R0402; R_0402_5MIL_DWS
R3, R4, R8, R9: 2.2k/R0402; R_0402_5MIL_DWS
R10: 220R/R0402; R_0402_5MIL_DWS
R11: 100k/R0402; R_0402_5MIL_DWS
R12: 22k/1%/R0402; R_0402_5MIL_DWS
R15: 220k/R0402; R_0402_5MIL_DWS
RST1: IT-1185AU2-160G-G-TR; IT1185AU2_V2
U1: BL4054B-42TPRN(SOT23-5); SOT-23-5
U2: CH340T(SSOP20W); SSOP-20W
U3: SY8089AAAC(SOT23-5); SOT-23-5
U4: Waveshare 1.5inch OLED display Module, 128x128 pixels
U5: ESP32-WROOM-32D-4MB; ESP32-WROVER_MODULE
X1: XKB8080-W

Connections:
+3V3: C7.1, J2.1, L1.2, R11.2, R13.1, R14.1, U5.2 (VDD33(3V3))
+5V: C1.1, CHARGING1.2 (A), D1.1 (K), D2.2 (A), FET1.1, R1.1, R15.1, U1.4 (VCC)
/+5V_USB: C4.1, D1.2 (A), J1.A4 (VBUS), J1.A9 (VBUS), J1.B4 (VBUS), J1.B9 (VBUS), R6.1, U2.19 (VCC)
/D_Com: D3.3 (CC), D_Com1.1 (Pad), R10.2
/ESP_EN: C8.1, Q2.3 (C), R13.2, RST1.1, U5.3 (EN)
/GPI35: C9.2, R2.2, R5.1, U5.7 (GPI35/ADC1_CH7/RTC_GPIO5)
/GPI39\SENSOR_VN: R15.2, R16.1, U5.5 (GPI39/SENSOR_VN/ADC1_CH3/ADC_H/RTC_GPIO3)
/GPIO0: D3.2 (A2), U5.25 (GPIO0/ADC2_CH1/TOUCH1/RTC_GPIO11/CLK_OU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)
/GPIO1\U0TXD: D5.1 (K), U5.35 (GPIO1/U0TXD/CLK_OUT3/EMAC_RXD2)
/GPIO2: D3.1 (A1), U5.24 (GPIO2/ADC2_CH2/TOUCH2/RTC_GPIO12/HSPIWP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)
/GPIO3\U0RXD: D4.2 (A), R17.2, U5.34 (GPIO3/U0RXD/CLK_OUT2)
/GPIO5: J2.5, U5.29 (GPIO5/VSPICS0/HS1_DATA6/EMAC_RX_CLK)
/GPIO13: C10.1, R14.2, U5.16 (GPIO13/ADC2_CH4/TOUCH4/RTC_GPIO14/MTCK/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), X1.4, X1.5, X1.6
/GPIO18: J2.4, U5.30 (GPIO18/VSPICLK/HS1_DATA7)
/GPIO19: J2.6, U5.31 (GPIO19/VSPIQ/U0CTS/EMAC_TXD0)
/GPIO23: J2.3, U5.37 (GPIO23/VSPID/HS1_STROBE)
/GPIO25: J2.7, U5.10 (GPIO25/DAC_1/ADC2_CH8/RTC_GPIO6/EMAC_RX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)
GND: BAT1.1, C1.2, C2.2, C3.2, C4.2, C5.2, C6.2, C7.2, C8.2, C9.1, C10.2, H1.1, H2.1, H3.1, H4.1, J1.A1 (GND), J1.A12 (GND), J1.B1 (GND), J1.B12 (GND), J1.S1 (SHIELD), J2.2, Q1.3 (case), R1.2, R4.2, R5.2, R12.2, R16.2, RST1.2, U1.2 (GND), U2.8 (GND), U3.2 (GND), U5.1 (GND), U5.15 (GND), U5.38 (GND), U5.39 (THERMAL_PAD), X1.1, X1.2, X1.3
unnamed: CHARGING1.1 (K), R3.1
unnamed: C6.1, D2.1 (K), FET1.2, U3.1 (EN), U3.4 (IN)
unnamed: D4.1 (K), U2.3 (TXD)
unnamed: D5.2 (A), R6.2, U2.4 (RXD)
unnamed: Q2.1 (B), R8.2
unnamed: Q2.2 (E), R9.1, U2.16 (RTS#)
unnamed: Q3.1 (B), R9.2
unnamed: Q3.3 (C), R10.1
unnamed: Q3.2 (E), R8.1, U2.15 (DTR#)
unnamed: R3.2, U1.1 (CHRGb)
unnamed: R4.1, U1.5 (PROG)
unnamed: J1.A6 (D+), J1.B6 (D+), U2.6 (UD+)
unnamed: J1.A7 (D-), J1.B7 (D-), U2.7 (UD-)
unnamed: C5.1, R17.1, U2.5 (V3)
unnamed: C2.1, Q1.1, U2.9 (XI)
unnamed: C3.1, Q1.2, U2.10 (XO)
unnamed: R11.1, R12.1, U3.5 (FB)
unnamed: L1.1, U3.3 (LX)
VBAT: BAT1.2, FET1.3, R2.1, U1.3 (VBAT)

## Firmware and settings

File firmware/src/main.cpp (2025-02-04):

#pragma once

#define LGFX_USE_V1

#include <nvs.h>
#include <nvs_flash.h>
#include <memory>
#include <esp_log.h>
#include <driver/i2c.h>
#include <soc/efuse_reg.h>
#include <soc/gpio_periph.h>
#include <soc/gpio_reg.h>
#include <soc/io_mux_reg.h>

#include "driver/uart.h"
#include "esp_timer.h"
#include "driver/gpio.h"
#include <string.h>
#include "esp_now.h"
#include "freertos/FreeRTOS.h"
#include "freertos/task.h"
#include "esp_wifi.h"
#include "esp_system.h"
#include "driver/adc.h"
#include "esp_adc_cal.h"
#include "esp_sleep.h"

#include <LovyanGFX.hpp>

#include <my_image_1.h>
#include <my_image_3.h>
//#include <connection_lost.h>

#define UART_NUM UART_NUM_1
#define UART_RX_BUFFER_SIZE 1024
#define TIMEOUT_THRESHOLD 3000  // 3 seconds, adjust as necessary
#define LCD_TIMEOUT_THRESHOLD 60000 // 20 seconds, adjust as necessary
#define STATUS_LED_GPIO 14  // Status LED is connected to GPIO 14
#define BUTTON_GPIO 13  // Button is connected to GPIO 0
#define EXTERNAL_POWER_GPIO 39  // External power is connected to GPIO 12
#define LED_GPIO 2      // LED is connected to GPIO 2
#define I2C_SDA_PIN 21 // I2C SDA pin
#define I2C_SCL_PIN 22 // I2C SCL pin
#define I2C_MASTER_NUM I2C_NUM_1    /*!< I2C port number for master dev */
#define I2C_MASTER_FREQ_HZ 100000   /*!< I2C master clock frequency */
#define SLEEP_THRESHOLD 600000 // 60 seconds, adjust as necessary

#define NVS_MAC_ADDRESS_KEY "mac_address"

#define COLOR_BLACK   0x0000
#define COLOR_WHITE   0xFFFF
#define COLOR_RED     0xF800
#define COLOR_GREEN   0x07E0
#define COLOR_BLUE    0x001F
#define COLOR_YELLOW  0xFFE0
#define COLOR_CYAN    0x07FF
#define COLOR_MAGENTA 0xF81F
#define COLOR_GRAY    0x8410
#define COLOR_DARKRED 0x8800
#define COLOR_DARKGREEN 0x0400
#define COLOR_DARKBLUE  0x0008

#define BATTERY_PIN       GPIO_NUM_35
#define ADC1_TEST_CHANNEL ADC1_CHANNEL_7
#define VREF              1100
#define FULL_BATTERY_VOLTAGE  4200 // in mV, adjust this based on your battery's specifications
#define EMPTY_BATTERY_VOLTAGE 3300 // in mV, adjust this based on your battery's specifications

// Constants for the polynomial fit
#define A_CONST 23.8
#define B_CONST -88.1
#define C_CONST 50

static esp_adc_cal_characteristics_t adc1_chars;

uint8_t current_status = 5;
static uint8_t led_state = 0;  // LED state
uint8_t previous_status = 0;
uint8_t peer_mac_address[6] = {0xb8, 0xd6, 0x1a, 0x42, 0x91, 0x2c};  // Peer MAC address
int64_t last_received_time = 0;
int64_t last_button_pressed_time = 0;
float external_voltage = 0.0;
bool external_power_connected = false;
float battery_charge_percentage = 0.0;

class LGFX : public lgfx::LGFX_Device
{
  lgfx::Panel_SSD1351     _panel_instance;
  lgfx::Bus_SPI       _bus_instance;   // SPIバスのインスタンス
  //lgfx::Light_PWM     _light_instance;
  //lgfx::Touch_FT5x06           _touch_instance; // FT5206, FT5306, FT5406, FT6206, FT6236, FT6336, FT6436

public:
  
  LGFX(void)
  {
    //PIN_PULLUP_DIS(IO_MUX_GPIO12_REG);

    { 
      auto cfg = _bus_instance.config();    // バス設定用の構造体を取得します。

      cfg.spi_host = VSPI_HOST;     // 使用するSPIを選択  ESP32-S2,C3 : SPI2_HOST or SPI3_HOST / ESP32 : VSPI_HOST or HSPI_HOST
      cfg.spi_mode = 3;             // SPI通信モードを設定 (0 ~ 3)
      cfg.freq_write = 10000000;    // 送信時のSPIクロック (最大80MHz, 80MHzを整数で割った値に丸められます)
      cfg.freq_read  = 5000000;    // 受信時のSPIクロック
      cfg.spi_3wire  = true;        // Set to true if reception is done on the MOSI pin
      cfg.use_lock   = true;        // Set true to use transaction lock
      cfg.dma_channel = SPI_DMA_CH_AUTO; // Set DMA channel to use (0=not use DMA / 1=1ch / 2=ch / SPI_DMA_CH_AUTO=auto setting)
      // With the ESP-IDF version upgrade, SPI_DMA_CH_AUTO (automatic setting) is recommended for the DMA channel. Specifying 1ch and 2ch is deprecated.
      cfg.pin_sclk = 18;            // SPIのSCLKピン番号を設定
      cfg.pin_mosi = 23;            // SPIのMOSIピン番号を設定
      cfg.pin_miso = -1;            // SPIのMISOピン番号を設定 (-1 = disable)
      cfg.pin_dc   = 19;            // SPIのD/Cピン番号を設定  (-1 = disable)
     // SDカードと共通のSPIバスを使う場合、MISOは省略せず必ず設定してください。


      _bus_instance.config(cfg);    // 設定値をバスに反映します。
      _panel_instance.setBus(&_bus_instance);      // バスをパネルにセットします。
    }

    { // 表示パネル制御の設定を行います。
      auto cfg = _panel_instance.config();    // 表示パネル設定用の構造体を取得します。

      cfg.pin_cs           =    5;  // CSが接続されているピン番号   (-1 = disable)
      //cfg.pin_cs           =    -1;  // CSが接続されているピン番号   (-1 = disable)
      cfg.pin_rst          =    25;  // RSTが接続されているピン番号  (-1 = disable)
      cfg.pin_busy         =    -1;  // BUSYが接続されているピン番号 (-1 = disable)

      // ※ 以下の設定値はパネル毎に一般的な初期値が設定されていますので、不明な項目はコメントアウトして試してみてください。

      cfg.panel_width      =   128;  // 実際に表示可能な幅
      cfg.panel_height     =   128;  // 実際に表示可能な高さ
      cfg.offset_x         =     0;  // パネルのX方向オフセット量
      cfg.offset_y         =     0;  // パネルのY方向オフセット量
      cfg.offset_rotation  =     0;  // 回転方向の値のオフセット 0~7 (4~7は上下反転)
      cfg.bus_shared       =  false;  // If the bus is shared with the SD card, set to true (bus control with drawJpgFile etc.)

      _panel_instance.config(cfg);
    }

/*

    { // バックライト制御の設定を行います。（必要なければ削除）
      auto cfg = _light_instance.config();    // バックライト設定用の構造体を取得します。

      cfg.pin_bl = 48;              // バックライトが接続されているピン番号
      cfg.invert = false;           // バックライトの輝度を反転させる場合 true
      cfg.freq   = 12000;           // バックライトのPWM周波数
      cfg.pwm_channel = 0;          // 使用するPWMのチャンネル番号

      _light_instance.config(cfg);
      _panel_instance.setLight(&_light_instance);  // バックライトをパネルにセットします。
    }



    { // タッチスクリーン制御の設定を行います。（必要なければ削除）
      auto cfg = _touch_instance.config();

      cfg.x_min      = 0;    // タッチスクリーンから得られる最小のX値(生の値)
      cfg.x_max      = 319;  // タッチスクリーンから得られる最大のX値(生の値)
      cfg.y_min      = 0;    // タッチスクリーンから得られる最小のY値(生の値)
      cfg.y_max      = 479;  // タッチスクリーンから得られる最大のY値(生の値)
      cfg.pin_int    = 40;   // INTが接続されているピン番号
      cfg.bus_shared = false; // 画面と共通のバスを使用している場合 trueを設定
      cfg.offset_rotation = 0;// 表示とタッチの向きのが一致しない場合の調整 0~7の値で設定

      cfg.i2c_port = 1;      // 使用するI2Cを選択 (0 or 1)
      cfg.i2c_addr = 0x38;   // I2Cデバイスアドレス番号
      cfg.pin_sda  = 38;     // SDAが接続されているピン番号
      cfg.pin_scl  = 39;     // SCLが接続されているピン番号
      cfg.freq = 400000;     // I2Cクロックを設定

      _touch_instance.config(cfg);
      _panel_instance.setTouch(&_touch_instance);  // タッチスクリーンをパネルにセットします。
    }
*/
    setPanel(&_panel_instance); // 使用するパネルをセットします。
  }
};

LGFX lcd;

void button_task(void* arg) {
    //gpio_set_direction(LED_GPIO, GPIO_MODE_OUTPUT);
    uint8_t status_saver = 0;
    
    while (1) {
        if (gpio_get_level((gpio_num_t)BUTTON_GPIO) == 1) { // Cnahged for NEW BUTTON
            printf("BUTTON PRESSED");
            char message[] = "BUTTON PRESSED";
            esp_now_send(peer_mac_address, (uint8_t*)message, sizeof(message));
            printf("Data sent to peer, MAC: %02X:%02X:%02X:%02X:%02X:%02X\n", peer_mac_address[0], peer_mac_address[1], peer_mac_address[2], peer_mac_address[3], peer_mac_address[4], peer_mac_address[5]);
            last_button_pressed_time = esp_timer_get_time() / 1000;
            lcd.invertDisplay(true);
            vTaskDelay(90 / portTICK_PERIOD_MS); // debounce delay
            lcd.invertDisplay(false);
            status_saver = current_status;
            current_status = 5;
            vTaskDelay(20 / portTICK_PERIOD_MS); // debounce delay
            current_status = status_saver;
            vTaskDelay(600 / portTICK_PERIOD_MS); // debounce delay
        }
        vTaskDelay(10 / portTICK_PERIOD_MS);  // polling delay
    }
}

void on_data_sent(const uint8_t *mac_addr, esp_now_send_status_t status) {
    //gpio_set_level(LED_GPIO, !gpio_get_level(LED_GPIO));
    printf("Data sent to peer\n");
}

void on_data_recv(const uint8_t *mac_addr, const uint8_t *data, int len) {
    // Make sure data is null-terminated
    char *str = (char *)malloc(len + 1);
    memcpy(str, data, len);
    str[len] = '\0';
    printf("MASTER:Received: %s\n", str);
    // Check if message contains status update
    char *status_loc = strstr(str, "Current status: ");
    char *mail_loc = strstr(str, "mail");
    char *contact_loc = strstr(str, "contact");
    char *application_loc = strstr(str, "application");
    char *emergency_loc = strstr(str, "emergency");
    char *link_loc = strstr(str, "link");
    char *call_loc = strstr(str, "call");
    if (status_loc != NULL) {
        // Extract the status value
        int status_value = atoi(status_loc + strlen("Current status: "));
        //printf("status: %d\n", status_value);
        if(status_value == 0 || status_value == 1){
            // Save the value to the corresponding variable
            current_status = status_value;
        }
    }
    // Check if message contains: mail, contact, application, emergency, link or call
    
    else if (mail_loc != NULL || contact_loc != NULL || application_loc != NULL || emergency_loc != NULL || link_loc != NULL || call_loc != NULL) {
        // Save the value to the corresponding variable
        //current_status = 2;
        //Convert received string to status code
        if (mail_loc != NULL){
            current_status = 2;
        }
        else if (contact_loc != NULL){
            current_status = 3;
        }
        else if (application_loc != NULL){
            current_status = 4;
        }
        else if (emergency_loc != NULL){
            current_status = 8;
        }
        else if (link_loc != NULL){
            current_status = 6;
        }
        else if (call_loc != NULL){
            current_status = 7;
        }
    }
    free(str);
    last_received_time = esp_timer_get_time() / 1000;

}

void init_wifi(){
    // Initialize WiFi
    tcpip_adapter_init();
    ESP_ERROR_CHECK(esp_event_loop_create_default());
    wifi_init_config_t cfg = WIFI_INIT_CONFIG_DEFAULT();
    ESP_ERROR_CHECK(esp_wifi_init(&cfg));
    ESP_ERROR_CHECK(esp_wifi_set_storage(WIFI_STORAGE_RAM));
    ESP_ERROR_CHECK(esp_wifi_set_mode(WIFI_MODE_STA));
    ESP_ERROR_CHECK(esp_wifi_start());

    // Get MAC address
    uint8_t mac[6];
    esp_efuse_mac_get_default(mac);

    // Print MAC address
    ESP_LOGI("WIFI", "MAC: %02X:%02X:%02X:%02X:%02X:%02X\n", mac[0], mac[1], mac[2], mac[3], mac[4], mac[5]);
}

void print_mac_address() {
    uint8_t mac[6];
    esp_efuse_mac_get_default(mac);
    ESP_LOGI("ADRESS", "MAC: %02X:%02X:%02X:%02X:%02X:%02X\n", mac[0], mac[1], mac[2], mac[3], mac[4], mac[5]);
}

void init_esp_now() {
    // Initialize ESP-NOW
    ESP_ERROR_CHECK(esp_now_init());
    ESP_ERROR_CHECK(esp_now_register_send_cb(on_data_sent));
    ESP_ERROR_CHECK(esp_now_register_recv_cb(on_data_recv));

    // Add peer
    esp_now_peer_info_t peer_info;
    memset(&peer_info, 0, sizeof(peer_info));
    peer_info.channel = 0;  
    peer_info.encrypt = false;
    memcpy(peer_info.peer_addr, peer_mac_address, 6);
    ESP_ERROR_CHECK(esp_now_add_peer(&peer_info));
}

esp_err_t init_nvs() {
    esp_err_t ret = nvs_flash_init();
    if (ret == ESP_ERR_NVS_NO_FREE_PAGES || ret == ESP_ERR_NVS_NEW_VERSION_FOUND) {
      ESP_ERROR_CHECK(nvs_flash_erase());
      ret = nvs_flash_init();
    }
    ESP_LOGI("NVS", "NVS init: %s", esp_err_to_name(ret));
    return ret;
}

esp_err_t save_mac_address(const uint8_t* mac_address) {
    nvs_handle_t nvs_handle;
    esp_err_t err = nvs_open("storage", NVS_READWRITE, &nvs_handle);
    if (err != ESP_OK) {
        
        ESP_LOGE("NVS", "Error opening NVS: %s", esp_err_to_name(err));
        return err;
    }

    err = nvs_set_blob(nvs_handle, NVS_MAC_ADDRESS_KEY, mac_address, 6);
    if (err != ESP_OK) {
        ESP_LOGE("NVS", "Error saving MAC address to NVS: %s", esp_err_to_name(err));
    }

    nvs_close(nvs_handle);
    return err;
}

esp_err_t read_mac_address(uint8_t* mac_address) {
    nvs_handle_t nvs_handle;
    esp_err_t err = nvs_open("storage", NVS_READWRITE, &nvs_handle);
    if (err != ESP_OK) {
        ESP_LOGE("NVS", "Error opening NVS: %s", esp_err_to_name(err));
        return err;
    }

    size_t required_size = 6;
    err = nvs_get_blob(nvs_handle, NVS_MAC_ADDRESS_KEY, mac_address, &required_size);
    if (err == ESP_OK && required_size == 6) {
        ESP_LOGI("NVS", "Read MAC address from NVS");
    } else if (err == ESP_ERR_NVS_NOT_FOUND) {
        ESP_LOGI("NVS", "MAC address not found in NVS.");
        err = nvs_set_blob(nvs_handle, NVS_MAC_ADDRESS_KEY, mac_address, 6);
        if (err != ESP_OK) {
            ESP_LOGE("NVS", "Error saving MAC address to NVS: %s", esp_err_to_name(err));
        }
    } else {
        ESP_LOGE("NVS", "Error reading MAC address from NVS: %s", esp_err_to_name(err));
    }

    nvs_close(nvs_handle);
    return err;
}

// Function to check if message contains one of prefixes stored in array
bool check_prefix(char *message, char **prefixes, int prefixes_size) {
    for (int i = 0; i < prefixes_size; i++) {
        if (strncmp(message, prefixes[i], strlen(prefixes[i])) == 0) {
            return true;
        }
    }
    return false;
}

void uart_task(void *pvParameters) {
    uint8_t uart_rx_buffer[UART_RX_BUFFER_SIZE];
    uint8_t mac_address[6];
    uint8_t mac_address_received = 0;

    // Set up UART configuration
    uart_config_t uart_config = {
        .baud_rate = 115200,
        .data_bits = UART_DATA_8_BITS,
        .parity = UART_PARITY_DISABLE,
        .stop_bits = UART_STOP_BITS_1,
        .flow_ctrl = UART_HW_FLOWCTRL_DISABLE
    };
    uart_param_config(UART_NUM_0, &uart_config);
    uart_driver_install(UART_NUM_0, UART_RX_BUFFER_SIZE * 2, 0, 0, NULL, 0);

    char *mac_prefix = "MAC: ";
    char *reboot_prefix = "REBOOT";
    char *ping_prefix = "PING";
    char *mail_prefix = "mail";
    char *contact_prefix = "contact";
    char *application_prefix = "application";
    char *emergency_prefix = "emergency";
    char *link_prefix = "link";
    char *call_prefix = "call";
        // Create an array of prefixes
    char *prefixes[] = {mail_prefix, contact_prefix, application_prefix, emergency_prefix, link_prefix, call_prefix};

    while (1) {
        int len = uart_read_bytes(UART_NUM_0, uart_rx_buffer, UART_RX_BUFFER_SIZE, 100 / portTICK_PERIOD_MS);
        if (len > 0) {
            // Process the received UART data here
            // Assume the data received is the MAC address in the format "MAC: xx:xx:xx:xx:xx:xx"
            
            if (strncmp((char *)uart_rx_buffer, mac_prefix, strlen(mac_prefix)) == 0) {
                if (sscanf((char *)uart_rx_buffer + strlen(mac_prefix), "%02hhX:%02hhX:%02hhX:%02hhX:%02hhX:%02hhX",
                           &mac_address[0], &mac_address[1], &mac_address[2], &mac_address[3], &mac_address[4], &mac_address[5]) == 6) {
                    // MAC address successfully extracted from UART message
                    mac_address_received = 1;
                    ESP_LOGI("UART", "Received MAC address:");
                    for (int i = 0; i < 6; i++) {
                        ESP_LOGI("UART", "%02X ", mac_address[i]);
                    }
                    ESP_LOGI("UART", "\n");

                    // Save the MAC address using the function from the previous answer
                    esp_err_t nvs_err = save_mac_address(mac_address);
                    if (nvs_err == ESP_OK) {
                        ESP_LOGI("UART", "MAC address saved to NVS.");
                    }
                }
            }
            else if (strncmp((char *)uart_rx_buffer, reboot_prefix, strlen(reboot_prefix)) == 0) {
                ESP_LOGI("UART", "Rebooting...");
                esp_restart();
            }
            else if (strncmp((char *)uart_rx_buffer, ping_prefix, strlen(ping_prefix)) == 0) {
                ESP_LOGI("UART", "Ping received!");
                last_received_time = esp_timer_get_time() / 1000;
            }
            else if (check_prefix((char *)uart_rx_buffer, prefixes, sizeof(prefixes) / sizeof(prefixes[0]))) {
                last_received_time = esp_timer_get_time() / 1000;
                // Set crresponding status code
                if (strncmp((char *)uart_rx_buffer, mail_prefix, strlen(mail_prefix)) == 0) {
                    current_status = 2;
                }
                else if (strncmp((char *)uart_rx_buffer, application_prefix, strlen(application_prefix)) == 0) {
                    current_status = 4;
                }
                else if (strncmp((char *)uart_rx_buffer, link_prefix, strlen(link_prefix)) == 0) {
                    current_status = 6;
                }
                else if (strncmp((char *)uart_rx_buffer, call_prefix, strlen(call_prefix)) == 0) {
                    current_status = 7;
                }
                else if (strncmp((char *)uart_rx_buffer, link_prefix, strlen(link_prefix)) == 0) {
                    current_status = 5;
                }
                
            }

            // Clear the UART buffer
            memset(uart_rx_buffer, 0, sizeof(uart_rx_buffer));
        }
    }
}


void init_display(void)
{
  lcd.init();

  lcd.setTextSize((std::max(lcd.width(), lcd.height()) + 255) >> 8);

  lcd.setRotation(4);

  lcd.fillScreen(TFT_BLACK);
}

void check_timeout_task(void *pvParameter) {
    char data_str[20] = {0};
    sprintf(data_str, "CONNECTION FAIL!");
    ESP_LOGI("TIMEOUT", "Timeout task started!");
    uint8_t timeout_message_counter = 0;
    int64_t current_time = esp_timer_get_time() / 1000;
    int64_t time_diff = current_time - last_received_time;
    while (1) {
        current_time = esp_timer_get_time() / 1000;
        time_diff = current_time - last_received_time;
        if (time_diff > TIMEOUT_THRESHOLD) {
                current_status = 3; // Timeout status code
                timeout_message_counter++;
                if (timeout_message_counter == 100){
                    ESP_LOGI("TIMEOUT", "No responce from display device!");
                    timeout_message_counter = 0;
                }  
        }
        //ESP_LOGI("TIMEOUT", "Current status: %" PRId64, time_diff);
        vTaskDelay(100 / portTICK_PERIOD_MS);  // check every second
    }
}

void send_periodic_ping(void *pvParameter) {
    char data_str[20] = {0};
    sprintf(data_str, "PING");
    ESP_LOGI("PING", "PING task started!");
    while (1) {
        esp_now_send(peer_mac_address, (uint8_t*)data_str, sizeof(data_str));
        ESP_LOGI("PING", "PING sent to peer, MAC: %02X:%02X:%02X:%02X:%02X:%02X", peer_mac_address[0], peer_mac_address[1], peer_mac_address[2], peer_mac_address[3], peer_mac_address[4], peer_mac_address[5]);
        vTaskDelay(1000 / portTICK_PERIOD_MS);  // send every 1000 ms
    }
}

void draw_power_saving_screen(void){
    lcd.clearDisplay();
    lcd.setTextColor(COLOR_WHITE);
    lcd.drawString("POWER SAVING MODE", 14, 24);
    lcd.drawString("PUSH TO WAKE UP", 19, 54);
    if (battery_charge_percentage > 50){
        lcd.setTextColor(COLOR_GREEN);
    }
    else if (battery_charge_percentage > 20){
        lcd.setTextColor(COLOR_YELLOW);
    }
    else {
        lcd.setTextColor(COLOR_RED);
    }
    lcd.drawString("BATTERY: ", 27, 104);
    lcd.drawNumber(battery_charge_percentage, 77, 104);
    lcd.drawString("%", 100, 104);
    if (external_power_connected == true){
        lcd.setTextColor(COLOR_YELLOW);
        lcd.drawString("CHARGING", 40, 114);
    }
}
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
extern "C" void app_main() {
    // Initialize display
    init_display();
    drawSunrise();
    // Configure button GPIO
    config_button_gpio();
    // Callibrate adc
    esp_adc_cal_characterize(ADC_UNIT_1, ADC_ATTEN_DB_11, ADC_WIDTH_12Bit, 0, &adc1_chars);
    // Initialize NVS
    ESP_ERROR_CHECK(init_nvs());
    // Read MAC address from NVS
    ESP_ERROR_CHECK(read_mac_address(peer_mac_address));
    // Initialize wifi
    init_wifi();
    // Initialize ESP-NOW and register callbacks
    init_esp_now();
    // Initialize timer
    last_received_time = esp_timer_get_time() / 1000;
    // Create tasks
    xTaskCreate(button_task, "button_task", 1024 * 2, NULL, 1, NULL);
    xTaskCreate(uart_task, "uart_task", 4096 * 2, NULL, 1, NULL);
    xTaskCreate(check_timeout_task, "check_timeout_task", 1024 * 2, NULL, 1, NULL);
    xTaskCreate(status_display, "status_display", 1024 * 2, NULL, 1, NULL);
    xTaskCreate(check_lcd_timeout_task, "check_lcd_timeout_task", 1024 * 2, NULL, 1, NULL);
    xTaskCreate(battery_monitor_task, "battery_monitor_task", 1024 * 2, NULL, 1, NULL);
    xTaskCreate(external_power_monitor_task, "external_power_monitor_task", 1024 * 2, NULL, 1, NULL);
    xTaskCreate(sleep_monitor_task, "sleep_monitor_task", 1024 * 2, NULL, 1, NULL);
    xTaskCreate(send_periodic_ping, "send_periodic_ping", 1024 * 2, NULL, 1, NULL);
    print_mac_address();
}

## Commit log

2025-02-04 Initial push
    [1.44in SPI LCD Module - No Glass.stp, BAT54.step, Button_top_v2.stl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]
2025-02-05 Updated readme, added drawings
    [Assembly.FCStd, enclosure.FCStd, lid.FCStd]
